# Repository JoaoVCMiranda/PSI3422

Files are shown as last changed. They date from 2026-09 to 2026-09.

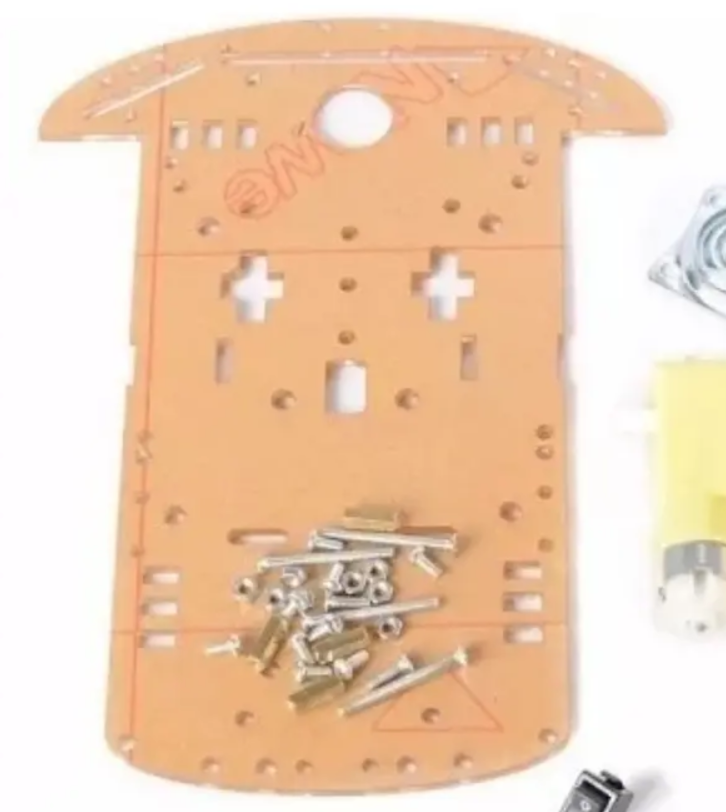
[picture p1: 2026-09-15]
experiências/Exp3_PSI3422/assets/desenho_chassi.png

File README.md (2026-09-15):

# Laboratório de Sistemas Eletrônicos

## Exp1 - Profª Yu

### Aula 1
- [X] Entregue, porém podemos fazer melhor

Objetivos:

    Programar o carrinho para: avançar, recuar e fazer curvas.
    Detectar obstáculos e desviar-se deles.

Roteiro:

    Conecte a ponte H aos motores e programe o carrinho para avançar/recuar;
    Controle a velocidade dos motores para fazer curvas.
    Programe o sensor ultrassom para detectar obstáculos e desviar-se deles. 

Última atualização: terça-feira, 4 ago. 2026, 08:45

### Aula 2
- [X] Entregue — ver `experiências/Exp2_PSI3422/` (Carrinho + Controle, nRF24L01+ via `lib/spi` e `lib/nrf24` compartilhadas)
Objetivos:

    Implementar a comunicação serial entre duas placas de desenvolvimento Freedom (KL25Z) utilizando os tranceivers nRF24L01+.
    Através do terminal do computador, controlar remotamente um LED na outra placa Freedom.

Roteiro:

    Implemente a comunicação serial entre duas placas de desenvolvimento Freedom (KL25Z) utilizando os tranceivers nRF24L01+.
    Conecte os dois transceptores às duas placas Freedom de acordo com as orientações da apresentação.
    OBS1: Lembre-se que a tensão máxima de alimentação do nRF24L01+ é de 3,6!
    OBS2: Verifique a versão do seu módulo nRF24L01, pois os pinos mudam dependendo da versão do componente.
    Programe os transceptores para receber/trasmitir dados.
    Conecte as duas placas no mesmo computador e utilize o Serial Monitor para verificar a comunicação.
    Através do terminal do computador, controle remotamente um LED na outra placa Freedom.

Observações:

    Os transceptores utilizam a comunicação SPI.
    Freedom KL25Z suporta a comunicação SPI.
    Além da comunicação SPI, os pinos CE e CSN (IRQ opcional) precisam ser configurados para transmitir/receber dados.
    Os comandos de operação estão listados no Datasheet do módulo.
    A apresentação mostra de forma sucinta como programar cada modo de operação do módulo.

Última atualização: terça-feira, 11 ago. 2026, 09:19 

### Aula 3 
- [X] Ficou massa!
Objetivos:

    Criar uma placa de circuito impresso para interconectar os módulos que serão usados no carrinho.
    Usando esta placa, o carrinho deverá receber um comando remoto para movimentar os motores.
    O carrinho deverá ser alimentado pela bateria.

Observações:

    Defina quais pinos serão utilizados por cada componente antes de criar a placa de circuito impresso.
    Tamanho recomendado para os furos das ilhas: 2 mm
    Tamanho recomendado para as trilhas: 1 mm

Componentes:

    Microcontrolador FRDM KL25Z
    Sensor ultrassônico HC-SR04
    Módulo de comunicação wireless nRF24L01+
    Motores (Ponte H)
    Encoder dos motores (consulte os objetivos da "Aula 4" para verificar o uso dos encoders neste projeto)

Última atualização: segunda-feira, 17 ago. 2026, 16:32
### Aula 4 
Objetivos:

    Acople um encoder(sensor de obstáculos IR HW-201) em cada motor.

    Calibre o encoder para estimar a distância percorrida pelo carrinho.
    Calibre o encoder para controlar o movimento do carrinho e fazer:
        Uma curva de 90° para direita;
        Uma curva de 90° para esquerda.
    OBS: Essa parece uma aplicação interessante de programação competitiva, um código que dados dois contadores de rotações para cada roda, calcule qual é a distância percorrida.

Última atualização: segunda-feira, 17 ago. 2026, 16:32

### Aula 5 e 6
Objetivos:

    Monte o Shield e os módulos do carrinho.
    Programação do carrinho para atravessar o percurso fechado por obstáculos e estimar a distância percorrida.

Comportamento esperado do carrinho na entrega final/apresentação:
Controle remoto pelo computador:

    Controle o carrinho de forma remota através da comunicação wireless:
        Adicione um comando para entrar no estado RUN.
        Adicione um comando para entrar no estado STOP.
        Adicione um comando para mostrar a distância percorrida no computador.
        Adicione um comando para apagar a distância percorrida salvo no carrinho.

Funções no estado RUN:

    Crie uma lógica para o carrinho atravessar um labirinto.
    O carrinho pode avançar, recuar e fazer curvas.
    Estime e salve a distância percorrida (dar meia-volta não reduz a distância percorrida).

Funções no estado STOP:

    O carrinho fica parado e aguarda novas instruções.

Última atualização: segunda-feira, 17 ago. 2026, 19:55

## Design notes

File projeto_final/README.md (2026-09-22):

# projeto_final — consolidação de produção (Aulas 3-6)

Reúne os módulos "de produção" do carrinho — firmware, portmap único
e o ponto de partida da PCB — cobrindo o roteiro das Aulas 3 a 6 do
`README.md` raiz. Arquitetura: par **Carrinho + Controle** (like
`experiências/Exp2_PSI3422/`), não um board único — ver módulos abaixo.

## Fonte única do portmap

`pinmap.yaml` é a fonte de verdade dos pinos da FRDM-KL25Z (Carrinho
e Controle). `python3 tools/gen_pinmap.py` (de dentro desta pasta)
gera, de forma determinística:

- `pinmap.h` — incluído por `Carrinho/src/main.c` e
  `Controle/src/main.c`.
- `Pinmap.md` — tabela por board (substitui a manutenção manual
  duplicada em `experiências/Exp2_PSI3422/Pinmap.md` e
  `experiências/Exp4_PSI3422/pinmap.md`).
- `kicad/PSI3422_shield.kicad_sym` — símbolo KiCad do shield, ainda
  não reconciliado com o projeto KiCad de verdade (`kicad/Aula3_PCB.*`,
  movido de `experiências/Exp3_PSI3422/Kicad/`) — ver `kicad/README.md`
  pro estado de cada um e o próximo passo (validar no KiCad, que já
  está instalado nesta máquina agora, e unificar os dois símbolos).

Editar `pinmap.yaml`, nunca os três arquivos gerados.

## Protocolo — `protocol.h`

Extensão mínima de `experiências/Exp2_PSI3422/protocol.h`: RUN/STOP
reaproveitam `auto_mode`/`freio` (já existiam); dois campos novos —
`apagar_seq` (comando) e `dist_percorrida_cm` (telemetria) — cobrem
"mostrar distância"/"apagar distância" do roteiro. Ver comentários em
`protocol.h` pro racional de cada um.

## Carrinho/

Zephyr, FRDM-KL25Z. Junta `experiências/Exp2_PSI3422/Carrinho`
(motores, ultrassom, rádio, `lib/control_fsm`) com
`experiências/Exp4_PSI3422/CarrinhoBase` (encoder + `lib/odometria`)
por cima, sem mudar a lógica de nenhum dos dois — só a fiação entre
eles em `src/main.c`. `lib/control_fsm/` é cópia verbatim do Exp2 (não
precisou de mudança: "apagar distância" é tratado direto em
`main.c`, não dentro do FSM).

Só `ENCODER_R` está no pinmap atual — o carrinho não tem mais o
encoder esquerdo fisicamente montado. `lib/odometria` (contrato de
odometria diferencial, dois deltas) não foi alterada: `src/main.c`
passa o delta de `ENCODER_R` pros dois parâmetros, o que zera
`theta_rad` (campo não usado hoje) e mantém `distancia_percorrida_m`
correta. Ver comentário no topo de `Carrinho/src/main.c`.

**RUN** = `auto_mode` (desvio reativo por ultrassom frontal, 4
faixas) — é a "travessia de labirinto" cabível com um único sensor de
distância (frontal, sem mapeamento). **STOP** = `freio`.

### Parâmetros do carrinho

Distância entre as rodas: 17cm
Raio da roda: 3.5cm

## Controle/

Cópia de `experiências/Exp2_PSI3422/Controle` com duas teclas novas
em `key_to_cmd()`/`main()`: `i` (mostrar distância percorrida,
imprime a última telemetria já em cache — sem round-trip de rádio
novo) e `c` (apagar distância). `w/a/s/d/x/espaço/q/o` seguem iguais;
`o`/`x` agora nomeados explicitamente RUN/STOP no banner de boot.

Joystick continua desabilitado no código (defeito de hardware
confirmado, ver `experiências/Exp2_PSI3422/PENDENCIAS.md`) — UART
(`script/controle_serial.py`) é o caminho de comando.

## Monitoramento/

Terceiro board: só rádio nRF24L01+ em modo recepção — ouve a
telemetria (`radio_telemetry_t`) que o Carrinho já transmite a cada
ciclo (~50ms) e imprime `dist`/`dutyL`/`dutyR`/`percorrida`, sem
transmitir nenhum `radio_cmd_t` (isso continua sendo papel exclusivo
do Controle). Primeiro passo do roteiro de debug em ciclos rápidos:
recepção de metadados -> conferir contagem de distância -> conferir
o modelo de desvio do Carrinho resolvendo o percurso -> percurso real
(geometria a definir).

Mesmo pinmap de rádio/LEDs de Carrinho/Controle (`../pinmap.h`).
CAVEAT não validado em bancada: endereço/canal do nRF24 são únicos e
fixos pro projeto inteiro (`lib/nrf24/nrf24.c`) e auto-ACK está
ligado — com três rádios (Carrinho, Controle, Monitoramento) no
mesmo endereço/canal, Monitoramento passa a mandar ACK pros pacotes
do Carrinho ao mesmo tempo que o Controle, o que pode colidir no ar
e aumentar reenvios/timeouts vistos pelo Carrinho. Não deveria
derrubar o link (retransmissão já existe), mas fica por confirmar
com os três rádios ligados juntos.

## Pendente (fora desta rodada)

- ~~**`nrf24_init()` sempre retornava -134 (-ENOTSUP)**~~ RESOLVIDO
  (sessão de 22/09/2026) — provável causa raiz de TODO o histórico de
  "rádio não conecta" do projeto. `nrf24_init()` chamava
  `gpio_pin_interrupt_configure_dt(&nrf24_irq, GPIO_INT_EDGE_TO_ACTIVE)`
  em RADIO_IRQ (PTB8, PORTB). Neste board/framework
  (`dts/arm/nxp/nxp_kl25z.dtsi`), só `gpioa` (PORTA) e `gpiod`
  (PORTD) têm a property `interrupts` — `gpiob`/`gpioc`/`gpioe` não;
  o driver (`drivers/gpio/gpio_mcux.c`) só liga `GPIO_INT_ENABLE`
  quando essa property existe, e sem ela
  `gpio_pin_interrupt_configure()` retorna `-ENOTSUP` (-134) pra
  qualquer pino do port. Como RADIO_IRQ está em PORTB, essa chamada
  **sempre falhava**, e o `if (ret < 0) return ret;` logo depois
  fazia `nrf24_init()` abortar ali — `nrf24_configure()` (endereço,
  canal, CRC) nunca rodava, CE nunca ia pra 1: o rádio nunca foi
  configurado de verdade, em nenhum board, em nenhuma sessão. A
  interrupção era código morto (o semáforo que ela dispararia nunca
  era esperado em lugar nenhum — `nrf24_send()`/`nrf24_receive()` só
  fazem polling direto de `gpio_pin_get_dt()`), removida de
  `lib/nrf24/nrf24.c` — RADIO_IRQ agora só é `GPIO_INPUT` comum, sem
  callback/interrupção. `pio run` verificado em todos os projetos que
  usam `lib/nrf24` depois do fix. Ainda sem validação de bancada —
  mas isso muda completamente a prioridade dos diagnósticos SPI
  (`nrf24_read_status()`) e de timing/protocolo levantados antes:
  aquilo tudo era irrelevante enquanto o rádio nem chegava a ser
  inicializado.
- ~~**Dois pinmaps (`pinmap.yaml` vs `pinmap_carrinho.yaml`)**~~
  RESOLVIDO (sessão de 22/09/2026): a hipótese era que a PCB do
  Carrinho tinha o nRF24 fiado em PTD6/PTB9/PTD7 (commit 6e70945),
  diferente do Controle (fiado à mão em PTC5/PTC6/PTC7, o que
  `pinmap.yaml` atual documenta). `nrf24_read_status()` confirmou:
  status travado em `0xFF` nos DOIS boards — SPI0 de hardware só
  existe em PORTC/PORTA nesta família de chip, então PTD6/PTB9/PTD7
  nunca poderia funcionar por SPI0 em nenhum dos dois. Os fios do
  módulo nRF24 foram movidos fisicamente pra PTC5/PTC6/PTC7 nos dois
  boards — `debug_projeto_final`, `debug_projeto_final_controle` e
  `projeto_final/Carrinho` voltaram a usar `pinmap.h` (não
  `pinmap_carrinho.h`). `pinmap_carrinho.yaml`/`.h`/`.md`/símbolo
  KiCad ficam só como registro histórico do que a PCB tinha antes do
  rework, não são mais a referência ativa. `tools/gen_pinmap.py`
  continua aceitando um YAML alternativo como argumento, caso sirva
  de novo no futuro.
- ~~**RADIO_SCK/MOSI/MISO documentados errado em pinmap.yaml**~~
  RESOLVIDO (sessão de 22/09/2026): pinmap.yaml dizia PTD6/PTB9/PTD7,
  mas `nrf24_init()` chama `spi_init(SPI_0, ALT_0, ...)`
  (`lib/spi/spi.c`), que hardcoda PTC5/PTC6/PTC7 via CMSIS direto —
  as únicas duas rotas de hardware do SPI0 na KL25Z são PORTC (ALT_0)
  ou PORTA (ALT_1), então PTD6/PTB9/PTD7 nunca foi uma opção válida
  (erro de digitação antigo, não uma rota alternativa real).
  `pinmap.yaml`/`Pinmap.md` corrigidos pra PTC5/PTC6/PTC7 — esses
  pinos são `tipo: doc` (spi_init() não passa por devicetree, sem
  define em pinmap.h), então a correção não muda nenhum binário, só a
  documentação. **Mas se o shield físico foi roteado pelos valores
  antigos (PTD6/PTB9/PTD7), o SPI do rádio está fisicamente errado na
  placa** — conferir continuidade PTC5→SCK/PTC6→MOSI/PTC7→MISO do
  nRF24L01+ é prioridade de bancada, antes de qualquer outro debug de
  rádio (se for isso, explicaria falha de conexão de forma muito mais
  direta que qualquer hipótese de timing).
- ~~**Canais PWM dos motores trocados**~~ RESOLVIDO (sessão de
  22/09/2026): `debug/debug_ponte_H_encoder/src/main.c` já tinha
  descoberto e corrigido isso em bancada ("MOTOR_L_ENA_CH/MOTOR_R_ENB_CH
  estavam trocados"), mas a correção nunca voltou pro `pinmap.yaml` de
  produção. Confirmado de forma independente contra o datasheet
  (`MKL25Z128VLK4-pinctrl.dtsi`): PTD2 (MOTOR_L_ENA) é fisicamente
  TPM0_CH2, não CH1; PTA4 (MOTOR_R_ENB) é TPM0_CH1, não CH2. Com os
  canais trocados, o duty de cada motor saía fisicamente no pino do
  *outro* motor (direção in1/in2 continuava certa — só a velocidade
  ficava cruzada) — candidato forte pra explicar "carrinho anda torto"
  (PENDENCIAS.md do Exp2). `pinmap.yaml` corrigido e
  `pinmap.h`/`Pinmap.md` regerados via `gen_pinmap.py`; `pio run`
  verificado nos três projetos depois do fix. Ainda sem confirmação em
  bancada com o carrinho de verdade.
- ~~**Leitura dupla do ultrassom em auto_mode**~~ RESOLVIDO (mesma
  sessão): `Carrinho/src/main.c` já chama `ultrassom_read()` a cada
  ciclo (telemetria); `control_fsm_apply()` chamava de novo
  internamente em auto_mode, cada chamada bloqueando até
  `ECHO_TIMEOUT_MS` (30ms) — quase dobrava a latência da malha de
  desvio reativo. `control_fsm.c` agora reusa `sensor->distance` (já
  atualizado por main.c) em vez de disparar o sensor de novo.
- **`nrf24_receive(timeout)` era ignorado**: a implementação sempre
  esperava 100ms fixos, não importa o valor passado — sem efeito
  observável hoje (todo chamador usa `K_MSEC(100)`), mas quebraria em
  silêncio um `K_FOREVER`/outro valor. Corrigido em `lib/nrf24/nrf24.c`
  pra usar o `timeout` de verdade (`K_TICKS_FOREVER` tratado à parte).
- **Colisão de ACK com 3 rádios (caveat do `Monitoramento/`)**:
  mitigado, não eliminado — `lib/nrf24` ganhou `nrf24_set_auto_ack()`
  (liga/desliga EN_AA sem reconfigurar o resto do rádio) e
  `Monitoramento/src/main.c` desliga o próprio auto-ACK logo após
  `nrf24_init()` (e de novo a cada reconexão). Como Monitoramento só
  recebe, nunca precisou responder ACK — agora só o Controle responde,
  eliminando a colisão por construção em vez de só confiar em
  retransmissão. Ainda sem teste de bancada com os três rádios ligados
  juntos.
- ~~**Build verificado**~~ RESOLVIDO: causa raiz não era a máquina nem
  a instalação (pip vs. `uv tool install platformio`) — era
  `platform = freescalekinetis` sem versão em cada `platformio.ini`,
  que sempre resolve pra última release do registry. Isso "funcionava
  por acidente" enquanto a última release continuava pinando
  `framework-zephyr ~2.20701.0` (Zephyr 2.7.1, API antiga
  `#include <zephyr.h>`, a que todo o código daqui e do Exp2/Exp4
  usa). Em 31/08/2026 o registry publicou
  `freescalekinetis@11.0.0`, que pina `framework-zephyr ~3.40402.0`
  (Zephyr 4.4.2, exige `#include <zephyr/...>`) — dali em diante
  qualquer `pio run` nesta família de projetos passou a falhar,
  inclusive includes relativos (`../../protocol.h` etc.), porque a
  falha no primeiro `#include <zephyr.h>` aborta a unit de compilação
  antes de chegar nos outros. `Carrinho/`, `Controle/` e
  `Monitoramento/` agora pinam `platform = freescalekinetis@10.0.0`
  (última versão que pina Zephyr 2.7.1) em `platformio.ini` — `pio
  run` verificado com sucesso nos três (`[SUCCESS]`, firmware.elf/.bin
  gerados) nesta máquina. `experiências/Exp1-4_PSI3422/` continuam
  sem o pin — mesmo problema vai aparecer lá se alguém rodar `pio run`
  neles agora.
- **Validação de bancada**: RUN (desvio reativo) nunca rodou em
  carrinho de verdade (herdado do Exp2, ver PENDENCIAS.md); comandos
  `i`/`c` novos, sem teste com hardware. `Monitoramento/` (recepção
  de telemetria) também sem teste com hardware — inclui o caveat de
  colisão de ACK com três rádios, ver seção acima.
- **Calibração da odometria**: `Carrinho/src/main.c` atualizado para
  as medidas reais (17cm entre rodas, roda raio 3,5cm — ver seção
  "Parâmetros do carrinho" acima), substituindo as estimativas
  antigas (20cm/5cm) herdadas do Exp4. Ainda sem validação de bancada
  do valor absoluto de `dist_percorrida_cm` contra uma distância
  conhecida percorrida — é o próximo passo do roteiro (ver
  `Monitoramento/`, acima).
- **Chassi 3D**: decisão adiada (`experiências/Exp3_PSI3422/`,
  `modelo_1`/`modelo_2`) — fora do escopo desta rodada.
- **PCB**: `kicad/Aula3_PCB.kicad_pcb` já tem uma placa roteada, mas o
  esquemático (`.kicad_sch`) está praticamente vazio e o símbolo
  gerado (`PSI3422_shield.kicad_sym`) ainda não foi conciliado com o
  símbolo real (`FRDM-KL25Z.kicad_sym`) usado nela — validar abrindo
  no KiCad (já instalado) é o próximo passo, ver `kicad/README.md`.
- **Distância "salva"**: acumulador em RAM (`odometria_pose_t`), não
  sobrevive a reboot — suficiente pro roteiro por decisão explícita
  (sem NVS/flash).

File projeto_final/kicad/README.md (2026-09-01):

# kicad/ — PCB do shield

Dois conjuntos de arquivos aqui, ainda não reconciliados entre si
(próximo passo, ver "Pendente" no fim):

- **`Aula3_PCB.*`, `FRDM-KL25Z.kicad_sym`/`.kicad_mod`,
  `design-block-lib-table`, `model.png`** — projeto KiCad de verdade
  (movido de `experiências/Exp3_PSI3422/Kicad/`), com PCB já roteada
  (`Aula3_PCB.kicad_pcb`, ~5400 linhas) e um símbolo/footprint
  dedicado da FRDM-KL25Z. `Aula3_PCB.kicad_sch` ainda é praticamente
  vazio (13 linhas) — o trabalho até aqui parece ter ido direto pro
  editor de PCB.
- **`PSI3422_shield.kicad_sym`** — **gerado** por
  `../tools/gen_pinmap.py` a partir de `../pinmap.yaml` (mesma fonte
  que gera `../pinmap.h`, usado pelo código de `Carrinho`/`Controle`).
  Não editar à mão: editar o YAML e rodar
  `python3 tools/gen_pinmap.py` de dentro de `projeto_final/`.

KiCad 9.0.2 já está instalado nesta máquina (`kicad-cli` disponível) —
ainda não usei pra abrir/validar nenhum dos dois conjuntos de verdade,
fica pro próximo passo.

## Pendente (próxima rodada, avisado pelo usuário)

- **Validar** `Aula3_PCB.*` abrindo no KiCad de verdade — inclui
  conferir `design-block-lib-table`, que aponta pra um caminho
  absoluto do Windows (`C:/Users/caean/Desktop/FRDM-KL25Z ver6`,
  provavelmente de onde o símbolo/footprint originais vieram) —
  provavelmente inofensivo (metadado de biblioteca de "design
  blocks", não usado pelo `.kicad_pcb` em si) mas não confirmado ainda.
- **Single source of truth**: hoje `pinmap.yaml`/`gen_pinmap.py`
  geram um símbolo próprio (`PSI3422_shield.kicad_sym`) só com os
  sinais do portmap, separado do símbolo `FRDM-KL25Z` de verdade usado
  no `Aula3_PCB.kicad_sch`/`.kicad_pcb`. Reconciliar os dois é o
  próximo passo — provavelmente gerar os pinos DENTRO do símbolo
  `FRDM-KL25Z.kicad_sym` já usado na PCB real, em vez de manter dois
  símbolos paralelos.

## O que o gerador NÃO faz (trabalho manual que continua no KiCad)

- Adicionar os footprints dos outros componentes do shield: ponte H
  (L298N ou similar), HC-SR04, módulo nRF24L01+, os dois HW-201 —
  esses não têm pino fixo na KL25Z (são módulos externos conectados
  pelos sinais do símbolo gerado), então entram como símbolos/
  footprints padrão de biblioteca KiCad, não gerados daqui.
- Desenho elétrico dos módulos e roteamento físico exigem julgamento
  humano (posicionamento, trilhas de potência dos motores separadas
  das de sinal, etc.) — o gerador só resolve a parte mecânica de
  derivar pinos do portmap, não substitui isso.

Isso cobre a pendência da Aula 3 (`README.md` raiz) até o ponto onde
dá pra automatizar a partir do portmap.

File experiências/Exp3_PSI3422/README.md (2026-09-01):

Aqui haverá a modelagem feita em KiCAD para imprimirmos

E também o chassi modelado com o OpenSCAD

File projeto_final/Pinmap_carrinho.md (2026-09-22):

# Pinmap — projeto_final (FRDM-KL25Z)

GERADO por `tools/gen_pinmap.py` a partir de `pinmap.yaml` — não
editar à mão, editar o YAML e rodar o gerador de novo. Substitui a
manutenção manual de `experiências/Exp2_PSI3422/Pinmap.md` e
`experiências/Exp4_PSI3422/pinmap.md` (quase duplicados) por uma
fonte única, que também gera `pinmap.h` e o símbolo KiCad.

## Carrinho

| Sinal | Pino | Tipo/Direção | Observação |
|---|---|---|---|
| MOTOR_L_IN1 | PTD0 | saida | Ponte H, direção do motor esquerdo (lib/motor) |
| MOTOR_L_IN2 | PTC9 | saida | Ponte H, direção do motor esquerdo (lib/motor) |
| MOTOR_L_ENA | PTD2 | pwm | TPM0_CH2, velocidade do motor esquerdo, via lib/pwm_z42 (canal corrigido — ver debug/debug_ponte_H_encoder/src/main.c) |
| MOTOR_R_IN1 | PTC8 | saida | Ponte H, direção do motor direito (lib/motor) |
| MOTOR_R_IN2 | PTA5 | saida | Ponte H, direção do motor direito (lib/motor) |
| MOTOR_R_ENB | PTA4 | pwm | TPM0_CH1, velocidade do motor direito, via lib/pwm_z42 (canal corrigido — ver debug/debug_ponte_H_encoder/src/main.c) |
| ULTRASSOM_TRIG | PTD3 | saida | HC-SR04 trigger (lib/ultrassom) |
| ULTRASSOM_ECHO | PTD1 | entrada_irq | HC-SR04 echo, interrupção de borda (lib/ultrassom) |
| ENCODER_L | PTD1 | entrada_irq | IR HW-201 esquerda (lib/encoder) |
| ENCODER_R | PTA16 | entrada_irq | IR HW-201 direita (lib/encoder) |
| RADIO_SCK | PTD6 | fixo | valor de 6e70945 — ver aviso no topo do arquivo, spi_init() atual não bate com isso |
| RADIO_MOSI | PTB9 | fixo | idem RADIO_SCK |
| RADIO_MISO | PTD7 | fixo | idem RADIO_SCK |
| RADIO_CSN | PTB10 | saida | chip-select manual do nRF24 (lib/nrf24) |
| RADIO_CE | PTE31 | saida | lib/nrf24 |
| RADIO_IRQ | PTB8 | entrada_irq | ativo em LOW (lib/nrf24) |
| LED_RED | PTB18 | saida | active low |
| LED_GREEN | PTB19 | saida | active low |

## Controle

| Sinal | Pino | Tipo/Direção | Observação |
|---|---|---|---|
| RADIO_CSN | PTB10 | saida | chip-select manual do nRF24 (lib/nrf24) |
| RADIO_CE | PTE31 | saida | lib/nrf24 |
| RADIO_IRQ | PTB8 | entrada_irq | ativo em LOW (lib/nrf24) |
| LED_RED | PTB18 | saida | active low |
| LED_GREEN | PTB19 | saida | active low |
| CONSOLE_UART0 | PTA1 | fixo | PTA1/PTA2 (RX/TX), console fixo via devicetree (zephyr,console) — comandos via script/controle_serial.py |
| JOYSTICK_X | PTB0 | adc | ADC0_SE8 — defeito de hardware conhecido, ver PENDENCIAS.md |
| JOYSTICK_Y | PTB1 | adc | ADC0_SE9 |
| JOYSTICK_BTN | PTB2 | entrada | botão de freio, pull-up interno, active low |

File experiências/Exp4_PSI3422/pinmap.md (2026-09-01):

# Pinmap — Exp4_PSI3422 (CarrinhoBase, FRDM-KL25Z)

Mesmo chassi/pinagem de motores da Exp2_PSI3422 (ver `../Exp2_PSI3422/Pinmap.md`) — a Aula 4 só acopla os encoders IR HW-201, já reservados em PORTD desde a Exp2 (`debug/EncoderCheck`). Sem rádio nem ultrassom neste projeto: o escopo da Aula 4 é ponte H + contadores de volta com sinal, não o carrinho completo.

| Sinal | Pino | Observação |
|---|---|---|
| Motor L — IN1 | PTC8 | GPIO |
| Motor L — IN2 | PTC9 | GPIO |
| Motor L — ENA (PWM) | PTA4 | TPM0_CH1, via `lib/pwm_z42` |
| Motor R — IN1 | PTA12 | GPIO |
| Motor R — IN2 | PTD5 | GPIO |
| Motor R — ENB (PWM) | PTA5 | TPM0_CH2, via `lib/pwm_z42` |
| Encoder IR HW-201 — esquerda | PTD1 | GPIO entrada, interrupção de borda de subida |
| Encoder IR HW-201 — direita | PTD3 | GPIO entrada, interrupção de borda de subida |

`gpioc` não vem habilitado por padrão neste board (só `gpioa/b/d`) — ligado em `zephyr/boards/frdm_kl25z.overlay`, mesmo motivo do overlay da Exp2. `gpiod` já é default, não precisa de overlay para os encoders.

Encoders: mesma escolha de pino da Exp2 (PTD1/PTD3) — só PORTA e PORTC/PORTD geram interrupção por mudança de pino nesta subfamília KL25Z (PORTB/PORTE não, confirmado em bancada). Ver `lib/SPEC.md`, seção `encoder/`, para o racional de como o sentido (frente/ré) é inferido do comando do motor.

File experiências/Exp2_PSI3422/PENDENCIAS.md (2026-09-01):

# Pendências — Exp2_PSI3422

Snapshot do que falta, pra retomar sem precisar releer a conversa toda. `main` = entrega real (Atividade 2 já entregue, README Aula 2). `debug/exp2-validacoes` = bancada de validação, não mergeada.

## Hardware — bloqueando

- **Joystick (Controle) com defeito confirmado**: eixo travado perto de 3,3V/4095 (medido com multímetro e com `debug/JoystickCheck`). `joystick_read()` está desabilitado de novo no `main` (só UART funciona). Falta:
  - Rodar o teste de troca cruzada (trocar os fios X/Y) e o teste de continuidade no potenciômetro pra saber se é o pot ou a fiação do lado do KL25Z.
  - Depois de consertar, reativar a chamada comentada em `Controle/src/main.c` (`joystick_read(&ml, &mr, &brk);`) e revalidar com `debug/JoystickCheck`.

- **Carrinho anda torto** (uma roda com mais força/torque que a outra), confirmado com `debug/AlinhamentoCheck`. Já verificado que não é bug de firmware (`pwm_z42.c`/`motor.c` escrevem o mesmo duty nos dois canais TPM). Falta:
  - Rodar `debug/DutySweepCheck` (torque de arranque por motor) — construído, ainda não testado/reportado.
  - Rodar `debug/EncoderCheck` depois de instalar os HW-201 (pulsos/s por roda no mesmo duty) — construído, aguardando hardware.
  - Teste manual de troca cruzada dos motores (isola motor vs. ponte H/fiação) e teste com rodas no ar (isola elétrico vs. mecânico/atrito) — sugeridos, ainda não reportados.

## Branch debug/exp2-validacoes — não mergeada em main

- `JoystickCheck`, `AlinhamentoCheck`, `DutySweepCheck`, `EncoderCheck`, `monitor.py`: só existem aqui, não em `main`. Decidir quando (ou se) algo disso vale trazer pra `main` — provavelmente não os firmwares em si (são só bancada), mas:
- **Reserva de pinos dos encoders (PTD1/PTD3) no `Pinmap.md`** está só nesta branch. Levar pra `main` assim que os HW-201 forem instalados e `EncoderCheck` confirmar que os pinos funcionam de verdade.
- `debug/monitor.py`: comentário na linha ~73 ainda cita `DISTANCIA_MINIMA_M`, renomeada pra `DISTANCIA_FRENTE_M`/`DISTANCIA_CURVA_M`/`DISTANCIA_PARADA_M` no commit `4b3ff74` (main). Só comentário, não quebra nada — cosmético.

## auto_mode (control_fsm) — implementado, não testado com hardware real

Commit `4b3ff74` em `main` trocou o auto_mode binário por 4 faixas de distância (frente/vira direita/ré/para). Buildado com sucesso, mas **nunca rodado no carrinho de verdade** — validar:
- Os limiares (30/20/4cm) fazem sentido com o alcance/precisão real do HC-SR04 nesta montagem.
- O pivô de giro (`motor_l` frente + `motor_r` ré) realmente vira pra direita no sentido físico esperado (não foi conferido em bancada, só a lógica).
- Se `VELOCIDADE_AUTO` (~50%) é uma velocidade seguras pra virar/dar ré sem capotar ou perder tração.

## README — próximas aulas ainda não iniciadas

- **Aula 3** (`- [ ] Por Fazer`): projetar a PCB de verdade. `Pinmap.md` já cobre boa parte do "defina os pinos antes de criar a placa", mas falta o desenho da placa em si.
- **Aula 4** (sem checkbox — não iniciada): acoplar os HW-201, calibrar distância percorrida a partir da contagem de pulsos, fazer curvas de 90° calibradas. `debug/EncoderCheck` é um adiantamento de bancada pra isso, não a entrega.
- **Aula 5/6** (sem checkbox — não iniciada): comandos RUN/STOP remotos, travessia de labirinto, distância salva/apagável.

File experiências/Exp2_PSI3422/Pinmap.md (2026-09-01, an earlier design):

# Pinmap — Exp2_PSI3422 (Carrinho + Controle, FRDM-KL25Z)

Validado por build real (`pio run` em ambos os projetos) e pelos `#define` em cada `src/main.c` — não pelo diagrama Arduino do board (os headers D-numerados não batem com os pinos reais usados aqui).

Nem SPI nem TPM têm nó de devicetree neste port (Zephyr 2.7.1 empacotado pelo PlatformIO — conferido em `dts/arm/nxp/nxp_kl25z.dtsi`). Por isso o rádio usa `lib/spi` bare-metal em vez de `spi_dt_spec`, e os motores usam `pwm_z42` em vez de `pwm_dt_spec`. `gpioc`/`gpioe` também não vêm habilitados por padrão (só `gpioa/b/d`) — cada projeto liga isso em `zephyr/boards/frdm_kl25z.overlay`.

## Carrinho

| Sinal | Pino | Observação |
|---|---|---|
| Motor L — IN1 | PTC8 | GPIO |
| Motor L — IN2 | PTC9 | GPIO |
| Motor L — ENA (PWM) | PTA4 | TPM0_CH1, via `pwm_z42` |
| Motor R — IN1 | PTA12 | GPIO |
| Motor R — IN2 | PTD5 | GPIO |
| Motor R — ENB (PWM) | PTA5 | TPM0_CH2, via `pwm_z42` |
| Ultrassom — TRIG | PTD0 | GPIO saída |
| Ultrassom — ECHO | PTD4 | GPIO entrada, interrupção |
| Rádio — SCK/MOSI/MISO | PTC5/PTC6/PTC7 | SPI0 bare-metal (`lib/spi`, `ALT_0`) |
| Rádio — CSN | PTC4 | GPIO, chip-select manual |
| Rádio — CE | PTA13 | GPIO |
| Rádio — IRQ | PTD2 | GPIO entrada, interrupção ativa em LOW |
| LED status (vermelho/verde) | PTB18 / PTB19 | Active low |
| Encoder IR HW-201 — esquerda (reservado) | PTD1 | GPIO entrada, interrupção — ver `debug/EncoderCheck` |
| Encoder IR HW-201 — direita (reservado) | PTD3 | GPIO entrada, interrupção — ver `debug/EncoderCheck` |

Encoders: ainda não instalados fisicamente (Aula 4). Reservados em PORTD de propósito — nesta subfamília KL25Z só PORTA e PORTC/PORTD têm vetor de interrupção de pino; PORTB/PORTE não geram IRQ por mudança de pino (confirmado na bancada: `gpioe` como IRQ deu problema). PTD1/PTD3 ficam nos "buracos" entre os pinos de PORTD já usados (TRIG=PTD0, IRQ do rádio=PTD2, ECHO=PTD4, motor R IN2=PTD5), mesmo port já comprovado como fonte de interrupção.

## Controle

| Sinal | Pino | Observação |
|---|---|---|
| Rádio — SCK/MOSI/MISO | PTC5/PTC6/PTC7 | SPI0 bare-metal (`lib/spi`, `ALT_0`) |
| Rádio — CSN | PTC4 | GPIO, chip-select manual |
| Rádio — CE | PTA13 | GPIO |
| Rádio — IRQ | PTD2 | GPIO entrada, interrupção ativa em LOW |
| LED status (vermelho/verde) | PTB18 / PTB19 | Active low |
| Console (UART0) | PTA1/PTA2 | fixo, reservado, `printk` + comandos via `script/controle_serial.py` |
| Joystick — X | PTB0 | ADC0_SE8, `adc_channel_cfg`/`adc_sequence` (padrão de `PSI3441/entregas/4`) |
| Joystick — Y | PTB1 | ADC0_SE9, idem |
| Joystick — Botão de freio | PTB2 | GPIO entrada, pull-up interno, active low |

Pinos do joystick: não passaram por build real (`pio run`) ainda, só pelo padrão comprovado do PSI3441 Ativ.4 — nesta bancada o eixo já foi visto travado em 3,3 V/4095 (ver aviso em `Controle/src/main.c`).

## TPM disponível

A KL25Z tem 3 módulos TPM (`TPM0`: 6 canais, `TPM1`/`TPM2`: 2 canais cada — 10 no total). O Carrinho usa só 2 canais de `TPM0`; sobra folga para experiências futuras.

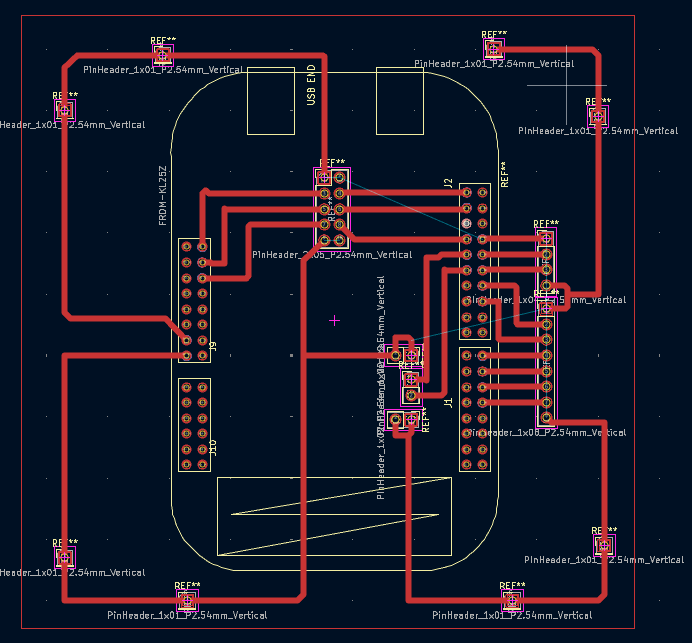
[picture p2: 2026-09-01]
projeto_final/kicad/model.png

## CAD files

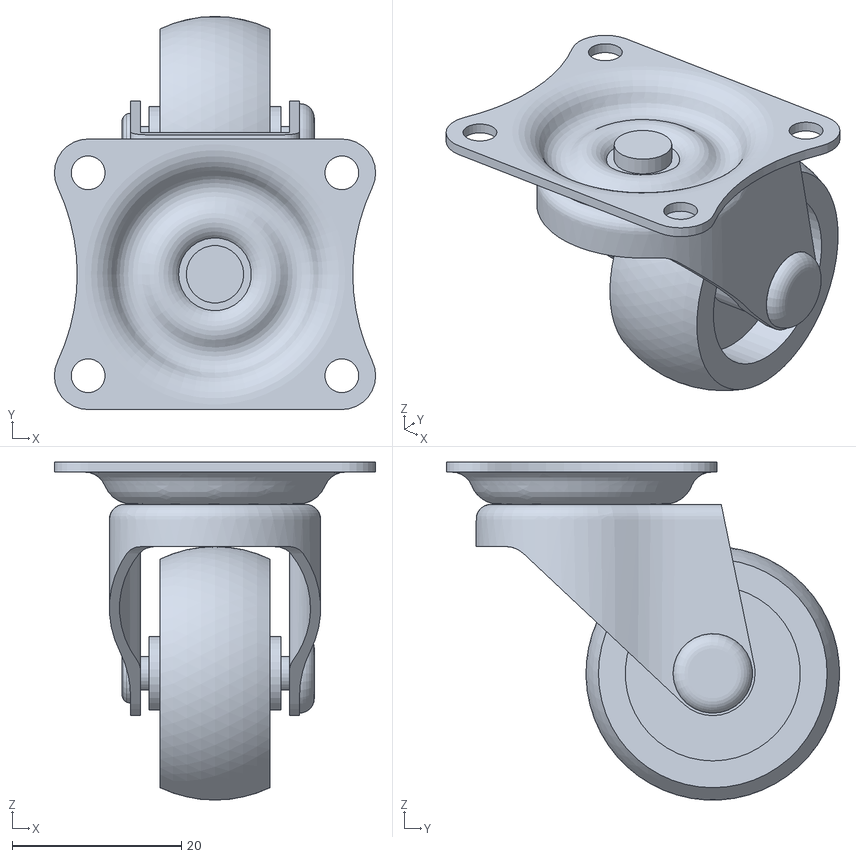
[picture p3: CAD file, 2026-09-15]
experiências/Exp3_PSI3422/assets/2wd_robot/caster.stl
38.0 x 46.5 x 40.0

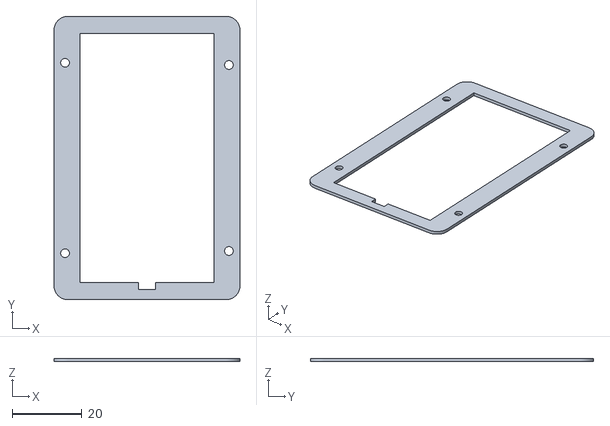
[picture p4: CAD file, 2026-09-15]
experiências/Exp3_PSI3422/assets/freescale_kl25z_drilling_guide.stl
53.3 x 81.3 x 1.00

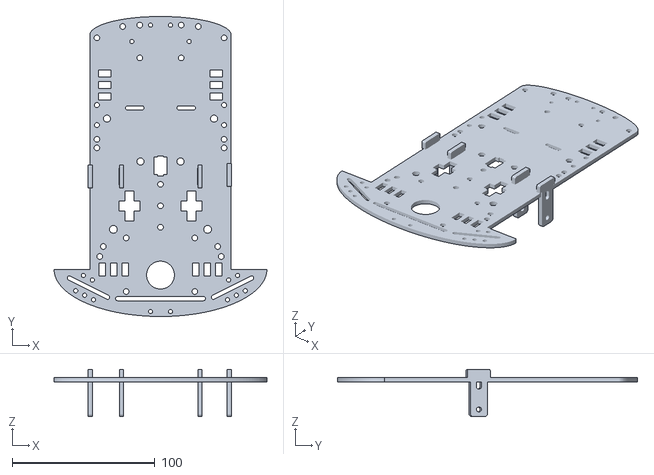
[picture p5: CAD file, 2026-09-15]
experiências/Exp3_PSI3422/assets/2wd_robot/chassis_plate.stl
149.0 x 210.0 x 33.0

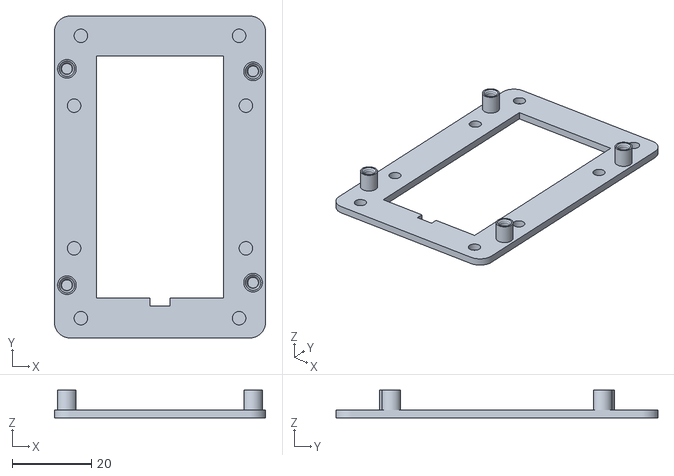
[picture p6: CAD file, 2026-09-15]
experiências/Exp3_PSI3422/assets/freescale_kl25z_mounting_plate.stl
53.3 x 81.3 x 7.00

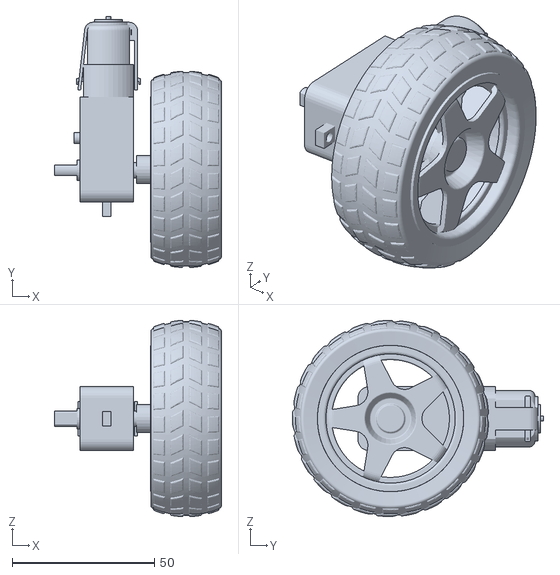
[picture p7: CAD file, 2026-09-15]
experiências/Exp3_PSI3422/assets/2wd_robot/motor_r.stl
58.8 x 88.2 x 68.9

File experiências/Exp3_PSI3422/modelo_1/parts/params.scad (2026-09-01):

include <BOSL2/std.scad>

$fs = 0.5;
$fa = 2;

// ============================================================
// PARÂMETROS DO CHASSI — Chassi 2WD REF: 7MS10 (MakerHero)
// Fonte única de verdade (mm). Valores marcados // ASSUNÇÃO foram
// estimados a partir da foto (assets/desenho_chassi.png) e das specs
// publicadas do kit, não de medição direta na peça física — conferir
// com paquímetro antes de mandar cortar a chapa definitiva.
// ============================================================

// --- Placa base (acrílico, corte a laser) ---
// A silhueta real vem de assets/2wd_robot/chassis_plate.stl (extraída do
// projeto de referência baixado pelo usuário — objeto "RobotChassis.001"
// isolado do .blend original via Blender). plate_length/plate_width abaixo
// são só a bounding box dessa peça real, usados como placeholder rápido
// durante $preview — a silhueta de verdade (com TODOS os furos e recortes
// originais do kit) é importada diretamente em base_plate.scad.
chassis_ref_stl       = "../assets/2wd_robot/chassis_plate.stl";
plate_length          = 210;  // bounding box real (medida no STL de referência)
plate_width           = 149;  // bounding box real
plate_thickness       = 3;    // spec do kit — ASSUNÇÃO (STL de referência não informa espessura real)

// --- Tração ---
// Coordenadas REAIS lidas no STL de referência (não são mais estimativa):
// os dois recortes em cruz do motor ficam em x=-100.05, y=±(48.5~52.3).
// NOTA IMPORTANTE: esse afastamento (~100mm entre os centros dos motores)
// diverge do wheelbase de 200mm medido no carrinho dos Exp2/Exp4 — ou o
// carrinho real não é um 7MS10 padrão, ou o valor medido é outra referência.
// PENDENTE de reconciliação com o firmware de odometria.
wheelbase_measured_exp2_4 = 200; // só documentado, não usado no modelo
wheel_diameter        = 68;   // spec do kit — diverge do raio 5cm (Ø100mm) do firmware, ver nota acima
wheel_width            = 26;   // spec do kit
motor_x_position         = -100.05; // REAL (STL de referência)
motor_y_offset            = 50.4;    // REAL (média dos dois furos em cruz, ±48.53/±52.26)

// --- Motores DC (70x37x23) — os recortes em cruz já existem na peça real,
// não precisam ser cortados por este modelo; só usamos o footprint p/ o
// preview 3D do motor+suporte. ---
motor_footprint           = [70, 37, 23];

// --- KL25Z (reaproveita os STLs existentes) — posicionado na área aberta
// do corpo principal da chapa (nariz, sem flare, oposto aos motores). ---
kl25z_footprint             = [53.34, 81.28];
kl25z_position                = [35, 0];
kl25z_rotation                 = 0;
kl25z_drilling_guide_stl        = "../assets/freescale_kl25z_drilling_guide.stl";
kl25z_mounting_plate_stl        = "../assets/freescale_kl25z_mounting_plate.stl";

// --- HW-201 (par, um por roda, medindo disco de marcação) ---
hw201_footprint                = [10, 32];  // ASSUNÇÃO
hw201_hole_d                    = 2.5;
hw201_x_offset_from_motor         = 22;     // desloca o sensor do motor em direção ao corpo (x = motor_x + offset)

// --- HC-SR04 (padrão de furação confirmado no datasheet do repo) ---
hcsr04_hole_spacing              = 16;
hcsr04_footprint                   = [45, 20];
hcsr04_hole_d                       = 2.5;
hcsr04_position                       = [80, 0]; // ponta do nariz (extremidade sem flare), sensor voltado p/ frente

// --- Driver ponte H (já fixado no chassi real — ASSUNÇÃO tipo L298N) ---
driver_footprint                    = [43, 43];
driver_height                        = 15;   // ASSUNÇÃO
driver_hole_inset                     = 3;
driver_position                        = [-32, 0];

// --- Roda caster ---
// O furo real (redondo, Ø≈19.5mm, x=-91.3 y=0, bem à frente dos motores)
// já existe na peça — não precisamos cortar nada, só desenhar o preview 3D.
caster_position                            = [-91.3, 0]; // REAL (STL de referência)
caster_diameter                             = 19.5;       // REAL
caster_height                                = 25;         // ASSUNÇÃO, p/ preview

// --- Baterias 9V (2 ou 3, opcionais — potência extra dos motores) ---
// Deitadas (comprimento na horizontal) para minimizar altura sobre a chapa.
battery9v_count                             = 2;    // 2 ou 3, ajustável
battery9v_body_footprint                     = [48.5, 26.5, 17.5]; // NEDA 1604/IEC 6LR61, deitada
battery9v_spacing                             = 30;  // entre eixos, ao longo de Y
battery9v_position                             = [-55, 15];

// --- Powerbank 5V (lógica) ---
// Sem cutout na chapa: fica sobre o andar superior (deck da PCB), preso por
// velcro — mais tolerante à falta de modelo definido e evita competir por
// espaço na chapa já congestionada.
powerbank_footprint                             = [100, 35, 15]; // ASSUNÇÃO, ajustar ao modelo escolhido
powerbank_mount_style                            = "velcro_on_deck";
powerbank_deck_offset                             = [0, 40]; // posição sobre o deck, relativa ao centro da PCB

// --- PCB própria (10x10cm, pedido do usuário) ---
// Fica em um andar superior sobre espaçadores impressos, acima de todos os
// componentes da chapa base (a bateria 9V deitada é o item mais alto, 17.5mm).
pcb_footprint                                     = [100, 100];
pcb_thickness                                      = 1.6;   // espessura padrão de PCB
pcb_hole_d                                          = 3;
pcb_standoff_footprint                               = [90, 70]; // onde os 4 pés pousam na chapa
pcb_hole_inset                                        = 8;
pcb_standoff_height                                    = 30;  // > altura da bateria 9V deitada (17.5mm) + folga
pcb_position                                            = [-10, 0]; // centralizado sobre motores/driver/baterias
pcb_on_upper_level                                       = true;

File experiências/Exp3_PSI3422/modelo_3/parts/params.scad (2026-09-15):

include <BOSL2/std.scad>

$fs = 0.5;
$fa = 2;

// ============================================================
// PARÂMETROS — modelo_3
//
// Mudança de abordagem em relação a modelo_1/2: a chapa é importada
// como SÓLIDO 3D real (assets/2wd_robot/chassis_plate.stl), sem
// achatar via projection()+linear_extrude e sem nenhuma rotação —
// usamos o referencial NATIVO do arquivo original (mesmo referencial
// do .blend baixado pelo usuário), para eliminar qualquer erro de
// transformação manual. Isso inverte length/width em relação a
// modelo_1/2:
//   X = largura do chassi (eixo lateral, ~149mm de ponta a ponta)
//   Y = comprimento do chassi / sentido de deslocamento (~210mm)
//   Z = altura (para cima)
//
// A posição dos motores e do rodízio vem de consulta direta ao
// .blend (bpy matrix_world.translation dos objetos "Motor",
// "Motor.001" e "Caster") — não são mais inferidas a partir de furos
// da chapa (essa inferência anterior, usada em modelo_1/2, estava
// desalinhada com a peça real, ver conversa).
// ============================================================

chassis_ref_stl       = "../assets/2wd_robot/chassis_plate.stl";

// --- Chapa: geometria real ---
// A chapa em si é fina (3mm, medido no histograma de vértices do STL:
// concentração maciça em Z=45 e Z=48, o resto são uns poucos pinos de
// alinhamento saindo dela) apesar da bounding box total (21.12-54.10)
// sugerir 33mm — isso é só a extensão desses pinos, não a chapa.
plate_top_z            = 48;    // REAL — superfície de cima da chapa
plate_bottom_z          = 45;    // REAL — superfície de baixo da chapa
plate_bbox_x            = [-76.36, 72.62];  // REAL, largura (X)
plate_bbox_y             = [-120.28, 89.69]; // REAL, comprimento (Y)

// --- Motores + rodas (posição REAL, lida do .blend) ---
// Os objetos "Motor"/"Motor.001" do .blend já incluem motor+roda como
// um único mesh (o Z bate exatamente com o diâmetro da roda). Usamos
// só a bounding box real deles para posicionar um cilindro (roda) +
// caixa (corpo do motor) simplificados — miniatura fiel o bastante,
// sem precisar importar os 16MB de cada malha real.
motor_l_center          = [-51.03, -32.97, 34.93]; // REAL (Motor)
motor_r_center           = [47.52, -32.97, 34.93]; // REAL (Motor.001)
motor_wheel_diameter      = 68.92; // REAL — bate com o Z-span do mesh (roda toca o chão em Z≈0.47)
motor_wheel_width          = 26;    // ASSUNÇÃO (largura da roda, não dá pra isolar do mesh combinado)
motor_body_footprint        = [37, 70, 23]; // ASSUNÇÃO (corpo do motor TT, X x Y x Z)

// --- Rodízio (posição REAL, lida do .blend) ---
caster_center             = [-2.00, 79.21, 25.77]; // REAL (objeto "Caster")
caster_footprint            = [38.00, 46.49, 39.98]; // REAL (dimensions do objeto)

// --- Ponte H L298N (embaixo da chapa) ---
l298n_footprint               = [43, 43, 26]; // spec típica do módulo L298N (incl. dissipador)
l298n_hole_inset                = 3;
l298n_position                    = [0, 10]; // área central aberta da chapa

// --- Sensor ultrassônico HC-SR04 ---
// CORRIGIDO no modelo_3: a maior dimensão (45mm) fica PERPENDICULAR
// ao sentido de deslocamento (Y) — ou seja, ao longo de X — e não mais
// alinhada com Y como em modelo_1/2. Fica na frente (Y alto, perto do
// rodízio) e voltado pra frente (+Y).
hcsr04_footprint_xy               = [45, 20]; // [X, Y] — 45 ao longo de X (perpendicular ao deslocamento)
hcsr04_hole_spacing                = 16;       // ao longo de X, mesmo eixo da maior dimensão
hcsr04_hole_d                       = 2.5;
hcsr04_height                        = 20;
hcsr04_position                       = [0, 78]; // entre a borda da PCB (y~30) e o rodízio (y~56) — frente da chapa

// --- FRDM-KL25Z ---
// Montada ACIMA do shield de PCB (não mais direto na chapa) — ver
// pcb_kl25z_gap abaixo.
kl25z_footprint                        = [53.34, 81.28];
kl25z_rotation                          = 0;
kl25z_drilling_guide_stl                 = "../assets/freescale_kl25z_drilling_guide.stl";
kl25z_mounting_plate_stl                  = "../assets/freescale_kl25z_mounting_plate.stl";

// --- PCB própria (shield, 10x10cm) ---
// Andar 1 (acima da chapa): PCB shield, sustentada por 4 pés impressos.
// Andar 2 (acima do shield): FRDM-KL25Z, empilhada por cima como um
// shield de Arduino.
pcb_footprint                            = [100, 100];
pcb_thickness                             = 1.6;
pcb_hole_d                                 = 3;
pcb_standoff_footprint                      = [90, 70]; // onde os 4 pés pousam na chapa
pcb_hole_inset                               = 8;
pcb_standoff_height                           = 30;  // chapa -> shield (folga da ponte H, que fica embaixo, e do L298N não interfere pq está embaixo tb)
pcb_position                                   = [0, -5]; // recuada p/ abrir espaço ao HC-SR04 na frente (ver hcsr04_position)
kl25z_standoff_height                           = 12;  // shield -> KL25Z (pequeno, tipo pino de shield)
kl25z_position_on_pcb                            = [0, 0]; // relativo ao centro da PCB

// --- HW-201 (par, um por roda) ---
// Cada um fica perto do respectivo motor/roda e aponta pra ela — a
// roda gira em torno do eixo X (perpendicular ao deslocamento Y), suas
// faces ficam voltadas para ±X, então o sensor "olha" ao longo de X.
hw201_footprint                                  = [10, 32]; // [ao longo de Y, altura]
hw201_hole_d                                      = 2.5;
hw201_y_offset_from_motor                          = 15; // desloca o sensor do motor em direção ao corpo (y = motor_y - offset)

// --- Módulo nRF24L01+ ---
// Encaixe simples (bolso de 3 paredes impresso) pra não ficar solto —
// só precisa posicionar a caixinha corretamente, sem parafusos.
nrf24_footprint                                     = [30.3, 14.5, 8]; // spec do módulo padrão c/ antena PCB
nrf24_pocket_wall                                     = 1.6;
nrf24_position_on_pcb                                  = [-30, 35]; // canto da PCB shield, relativo ao seu centro

// --- Baterias 9V (bocais/suportes, opcional — potência extra dos motores) ---
// Dimensão do SUPORTE completo (com tampa, sem plug — só a caixa),
// pesquisada em lojas de robótica BR: ~55x31x20mm por unidade.
battery9v_count                                        = 2;
battery9v_holder_footprint                              = [55, 31, 20]; // [X, Y, Z]
battery9v_spacing                                        = 35; // entre eixos, ao longo de X
battery9v_position                                        = [0, -75]; // área aberta atrás dos motores

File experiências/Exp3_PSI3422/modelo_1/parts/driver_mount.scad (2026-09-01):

include <params.scad>

module driver_mount_cutout() {
    translate(driver_position)
        for (sx = [-1, 1])
            for (sy = [-1, 1])
                translate([
                    sx * (driver_footprint[0] / 2 - driver_hole_inset),
                    sy * (driver_footprint[1] / 2 - driver_hole_inset)
                ])
                    circle(d = 3.2);
}

module driver_preview() {
    color("SteelBlue", 0.5)
        translate([driver_position[0], driver_position[1], driver_height / 2])
            cube([driver_footprint[0], driver_footprint[1], driver_height], center = true);
}

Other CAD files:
experiências/Exp3_PSI3422/assets/2wd_robot/motor_l.stl
experiências/Exp3_PSI3422/docs/aprendendo_openscad.scad
experiências/Exp3_PSI3422/modelo_1/chassi.scad
experiências/Exp3_PSI3422/modelo_1/parts/base_plate.scad
experiências/Exp3_PSI3422/modelo_1/parts/battery_holder.scad
experiências/Exp3_PSI3422/modelo_1/parts/caster_mount.scad
experiências/Exp3_PSI3422/modelo_1/parts/hcsr04_mount.scad
experiências/Exp3_PSI3422/modelo_1/parts/hw201_mount.scad
experiências/Exp3_PSI3422/modelo_1/parts/kl25z_mount.scad
experiências/Exp3_PSI3422/modelo_1/parts/motor_mount.scad
experiências/Exp3_PSI3422/modelo_1/parts/pcb_mount.scad
experiências/Exp3_PSI3422/modelo_1/parts/powerbank_mount.scad
experiências/Exp3_PSI3422/modelo_1/print/battery9v_cradle.scad
experiências/Exp3_PSI3422/modelo_1/print/hw201_bracket.scad
experiências/Exp3_PSI3422/modelo_1/print/pcb_standoff.scad
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

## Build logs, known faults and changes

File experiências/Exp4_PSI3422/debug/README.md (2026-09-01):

# debug/ — validações de bancada, fora da entrega

Firmwares isolados pra validar hardware sem depender do resto do
Exp4_PSI3422 — se algo não bate aqui, o problema é do sensor/fiação,
não da lib compartilhada (`../../../lib/encoder`,
`../../../lib/odometria`).

## IRHW201_ESP32

Flasha numa ESP32 avulsa (`upesy_wroom`) numa protoboard — não no
board do CarrinhoBase (KL25Z). Serial monitor: **115200 8N1**
(`monitor_speed` já no `platformio.ini`).

Objetivo não é medir PPS com motor girando (isso já foi validado em
`../../Exp2_PSI3422/debug/EncoderCheck`); é caracterizar o sensor
HW-201 isolado, na mão, antes de confiar no `GPIO_INT_EDGE_RISING`
assumido em `../../../lib/encoder/encoder.h`:

- nível de repouso do `OUT` com o feixe livre;
- qual borda (subida ou descida) corresponde a "feixe interrompido";
- se o sinal é limpo (sem bouncing) ao interromper o feixe manualmente
  (cartão/dedo no gap do sensor).

Fiação (HW-201, 3 pinos):

| HW-201 | ESP32 |
|---|---|
| VCC | 3V3 (**não** 5V — GPIO da ESP32 não é tolerante a 5V) |
| GND | GND |
| OUT | GPIO4 |

Rodar: `pio run -t upload -t monitor` dentro de `IRHW201_ESP32/`.

**Resultado confirmado em bancada** (protoboard, ESP32 + HW-201,
2026-09-01): `HIGH` = feixe livre, `LOW` = feixe interrompido. A
transição que marca "acabou de bloquear" é `FALLING`; a marca
"acabou de liberar" é `RISING`.

Saída de exemplo (feixe livre, depois interrompido à mão):

```
=== IRHW201_ESP32 -- debug de bancada do sensor IR HW-201 ===
Nivel de repouso (feixe livre) em GPIO4: HIGH
Interrompa o feixe com a mao/cartao e veja qual contagem sobe.
'intervalo_min' baixo (poucos us) e repetido = sinal de bouncing.

nivel=HIGH  subidas/s=  0  descidas/s=  0  intervalo_min=0 us
nivel=HIGH  subidas/s=  3  descidas/s=  3  intervalo_min=41207 us
nivel=HIGH  subidas/s=  0  descidas/s=  0  intervalo_min=0 us
```

Como ler:
- `subidas/s` e `descidas/s` sempre variam juntos (cada interrupção
  do feixe gera uma borda de cada tipo) — cada bloqueio soma 1 em
  ambos, então a contagem por segundo em si não é afetada pela
  polaridade.
- `intervalo_min` na casa de poucas centenas de µs, repetindo a cada
  interrupção manual do feixe, indicaria bouncing — não observado
  nesta bancada.
- Se `subidas/s`/`descidas/s` ficarem em 0 mesmo interrompendo o
  feixe, ajuste o trimpot do módulo até o LED dele reagir; se nada
  mudar, é falha do módulo, não do firmware.

**Sobre `lib/encoder/encoder.h`:** o código lá usa
`GPIO_INT_EDGE_RISING` — como cada bloqueio do feixe gera exatamente
uma borda de subida e uma de descida (mesma contagem por revolução
nos dois casos), a polaridade *não* muda quantos pulsos são contados,
só a fase (se o pulso é contado no instante em que bloqueia ou no
instante em que libera). Não é necessário alterar o código por causa
deste resultado — troca só faria sentido se algum dia a lib precisar
disparar exatamente no instante do bloqueio (ex.: medir duração do
bloqueio), o que a Aula 4 não pede.

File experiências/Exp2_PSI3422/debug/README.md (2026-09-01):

# debug/ — validações de bancada, fora da entrega

Firmwares Zephyr isolados pra validar hardware sem depender do resto
do Exp2_PSI3422 (rádio, control_fsm, etc.) — se algo não bate aqui, o
problema é de fiação/mecânica, não de lógica de controle. Vivem na
branch `debug/exp2-validacoes`, não em `main`.

Serial monitor: **115200 8N1**, não 9600 — `current-speed` no
`zephyr.dts` gerado pelo build (Carrinho, Controle e os três
firmwares daqui) é sempre `0x1c200` = 115200; `pio device monitor`
sem `--baud` já cai nesse default do board.

## monitor.py

Painel serial (`uv run monitor.py [porta] [--control]`) que lê a
saída de qualquer um dos firmwares (Carrinho, Controle, JoystickCheck,
AlinhamentoCheck), separa os tipos de log em métricas ao vivo
(telemetria, comando, joystick bruto, fase do AlinhamentoCheck,
erros/avisos) e, com `--control`, repassa w/a/s/d/x/espaço/q/o pra
UART do Controle — mesmo protocolo de
`../Controle/script/controle_serial.py`. Ver docstring do script pra
detalhes. As linhas `SWEEP ...` do DutySweepCheck ainda não têm painel
dedicado, caem no log bruto.

## JoystickCheck

Flasha no board do **Controle**. Lê X/Y do joystick (ADC) e o botão
de freio a cada 200ms e imprime bruto + o `motor_l`/`motor_r` que
`../Controle/src/main.c` derivaria.

Usa isso pra confirmar que o eixo não está preso em 3,3V/4095 (defeito
já visto nesta bancada, ver aviso em `../Controle/src/main.c`) antes
de confiar no joystick pra controlar o carrinho de verdade.

## AlinhamentoCheck

Flasha no board do **Carrinho**. Só motor + PWM (sem ultrassom, sem
rádio, sem control_fsm): manda o mesmo duty fixo (~50%) pros dois
motores por 3s, freia, pausa 2s, repete indefinidamente. Coloque o
carrinho no chão e observe se ele desvia pra um lado.

Como os dois motores recebem literalmente o mesmo valor, qualquer
desvio observado aqui é mecânico (roda torta, folga, atrito
desigual) — não dá pra atribuir a uma diferença de código entre os
dois lados.

## DutySweepCheck

Flasha no board do **Carrinho**. Testado depois do `AlinhamentoCheck`
mostrar o carrinho andando torto: sobe o duty de CADA motor sozinho
(o outro freado) em degraus de 0 até o máximo, ~1,5s por degrau, e
imprime o duty a cada passo. Levante o carrinho do chão e anote o
duty onde cada roda sai do lugar (torque de arranque) — se os dois
valores forem bem diferentes, é evidência objetiva de motor/ponte
H/fiação desigual, não só impressão visual.

Conferido antes de suspeitar de hardware: `pwm_z42.c`/`motor.c`
escrevem `CnV`/`CnSC` pelo mesmo código pros dois canais TPM, só
endereçando índices diferentes — duty comandado é garantidamente
idêntico em registrador nos dois motores.

## EncoderCheck

Flasha no board do **Carrinho**. Mesmo duty fixo nos dois motores
(igual `AlinhamentoCheck`), mas agora conta pulsos dos dois encoders
IR HW-201 (um por roda) e imprime pulsos/segundo (PPS) de cada lado a
cada 1s — dá um número real de rotação em vez de só observação
visual. Levante o carrinho do chão antes de ligar.

Encoders ainda não instalados fisicamente — pinos reservados em
PTD1 (esquerda) / PTD3 (direita), ver `../Pinmap.md`. De propósito
NÃO em PORTB/PORTE: nesta subfamília KL25Z só PORTA e PORTC/PORTD têm
vetor de interrupção de pino — foi exatamente o problema relatado ao
tentar usar `gpioe` como IRQ antes.

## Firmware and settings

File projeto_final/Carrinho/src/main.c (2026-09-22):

/*
 * PSI3422 — projeto_final / Carrinho
 *
 * Consolidação de produção: 2 motores DC (ponte H dupla) + ultrassom
 * HC-SR04 + rádio nRF24L01+ (base: experiências/Exp2_PSI3422/Carrinho)
 * com encoder IR HW-201 + odometria somados por cima (base:
 * experiências/Exp4_PSI3422/CarrinhoBase) — cobre o roteiro das
 * Aulas 5/6 (README.md raiz): RUN/STOP remotos, travessia de
 * labirinto por desvio reativo, distância percorrida que nunca
 * decresce, comando de apagar. Board: FRDM-KL25Z.
 *
 * Só ENCODER_R está no pinmap atual (ver ../../pinmap.yaml) — o
 * carrinho não tem mais o encoder esquerdo fisicamente montado.
 * lib/odometria continua a mesma (odometria diferencial, dois
 * deltas) — sem modificar o contrato dela (ver lib/SPEC.md), o delta
 * da roda direita é passado pros dois parâmetros, assumindo as rodas
 * andando junto (mesmo PWM nos dois motores fora de curva). Efeito:
 * `pose.theta_rad` fica sempre 0 (d_dir - d_esq cancela) — não tem
 * problema porque nada usa esse campo hoje (só
 * `distancia_percorrida_m` vai pra telemetria); `distancia_percorrida_m`
 * continua correta porque colapsa pra |d_dir| quando os dois deltas
 * são iguais.
 *
 * Pinos: ver ../../pinmap.h (gerado por ../../tools/gen_pinmap.py a
 * partir de ../../pinmap.yaml). RADIO_SCK/MOSI/MISO do módulo nRF24
 * foram movidos pra PTC5/PTC6/PTC7 em 22/09/2026 (nrf24_read_status()
 * mostrava 0xFF travado com o módulo em PTD6/PTB9/PTD7 — SPI0 de
 * hardware só existe em PORTC/PORTA nesta família de chip, nunca
 * poderia alcançar PTD6/PTB9/PTD7; ver ../../pinmap_carrinho.yaml
 * pro registro histórico do que a PCB tinha antes do rework).
 * Protocolo de rádio: ../../protocol.h.
 *
 * ── Arquitetura híbrida (GPIO Zephyr nativo, PWM/SPI bare-metal) e
 * por que um laço síncrono só (sem thread de rádio dedicada) ──
 * ver o comentário equivalente, mais longo, em
 * experiências/Exp2_PSI3422/Carrinho/src/main.c — inalterado aqui,
 * não repetido pra não desincronizar duas cópias do mesmo racional.
 *
 * RUN = auto_mode (desvio reativo por ultrassom frontal, 4 faixas —
 * ver lib/control_fsm/control_fsm.c). É a "travessia de labirinto"
 * cabível aqui: o carrinho só tem um sensor de distância (frontal),
 * não há como mapear o labirinto, só reagir ao obstáculo mais
 * próximo. Herdado de Exp2_PSI3422 sem mudança de lógica — por
 * PENDENCIAS.md daquele experimento, essa lógica nunca rodou em
 * carrinho de verdade, só buildou; validação de bancada fica pra
 * quando o hardware estiver montado.
 * STOP = freio (motores ignorados, carrinho parado).
 */

#include <zephyr.h>
#include <device.h>
#include <drivers/gpio.h>
#include <sys/printk.h>

#include "pwm_z42.h"
#include "motor.h"
#include "ultrassom.h"
#include "encoder.h"
#include "odometria.h"
#include "nrf24.h"
#include "control_fsm.h"
#include "../../protocol.h"
#include "../../pinmap.h"

/* TPM0 compartilhado pelos 2 canais de PWM dos motores: MCGIRCLK (4MHz,
 * independente do PLL) / PS_1 -> f_tpm = 4MHz; MOD=3999 -> f_pwm = 1kHz
 * (audível mas comum e seguro para motor DC via L298N). */
#define TPM_MOTOR_MOD 3999U

/* ── Calibração da odometria — medida em bancada, ver
 * ../README.md ("Parâmetros do carrinho": 17cm entre rodas, roda de
 * raio 3,5cm — este último bate com motor_wheel_diameter=68,92mm em
 * experiências/Exp3_PSI3422/modelo_3/parts/params.scad, medido do
 * .blend). Substitui os valores antigos (20cm/5cm) herdados de
 * experiências/Exp4_PSI3422/CarrinhoBase/src/main.c, que eram
 * estimativa, não medição do chassi real. pulsos/volta=1 (marco de
 * papel na roda) continua a confirmar girando N voltas em bancada —
 * ver control/relatorio-aula-4.md. ── */
#define DISTANCIA_ENTRE_RODAS_M 0.17f
#define PULSOS_POR_VOLTA 1
#define RODA_RAIO_M 0.035f
#define RODA_CIRCUNFERENCIA_M (2.0f * 3.14159265f * RODA_RAIO_M)

static motor_t motor_l;
static motor_t motor_r;
static ultrassom_t sensor;
static encoder_t encoder_r;
static odometria_pose_t pose;

void main()
{
    struct gpio_dt_spec l_in1 = { .port = MOTOR_L_IN1_PORT, .pin = MOTOR_L_IN1_PIN, .dt_flags = GPIO_ACTIVE_HIGH };
    struct gpio_dt_spec l_in2 = { .port = MOTOR_L_IN1_PORT, .pin = MOTOR_L_IN2_PIN, .dt_flags = GPIO_ACTIVE_HIGH };
    struct gpio_dt_spec r_in1 = { .port = MOTOR_R_IN1_PORT, .pin = MOTOR_R_IN1_PIN, .dt_flags = GPIO_ACTIVE_HIGH };
    struct gpio_dt_spec r_in2 = { .port = MOTOR_R_IN2_PORT, .pin = MOTOR_R_IN2_PIN, .dt_flags = GPIO_ACTIVE_HIGH };
    struct gpio_dt_spec trig  = { .port = ULTRASSOM_TRIG_PORT, .pin = ULTRASSOM_TRIG_PIN, .dt_flags = GPIO_ACTIVE_HIGH };
    struct gpio_dt_spec echo  = { .port = ULTRASSOM_ECHO_PORT, .pin = ULTRASSOM_ECHO_PIN, .dt_flags = GPIO_ACTIVE_HIGH };
    struct gpio_dt_spec enc_r = { .port = ENCODER_R_PORT, .pin = ENCODER_R_PIN, .dt_flags = GPIO_ACTIVE_HIGH };
    struct gpio_dt_spec ce    = { .port = RADIO_CE_PORT, .pin = RADIO_CE_PIN, .dt_flags = GPIO_ACTIVE_HIGH };
    struct gpio_dt_spec csn   = { .port = RADIO_CSN_PORT, .pin = RADIO_CSN_PIN, .dt_flags = GPIO_ACTIVE_LOW };
    struct gpio_dt_spec irq   = { .port = RADIO_IRQ_PORT, .pin = RADIO_IRQ_PIN, .dt_flags = GPIO_ACTIVE_LOW };

    struct gpio_dt_spec led_red = { .port = LED_RED_PORT, .pin = LED_RED_PIN, .dt_flags = GPIO_ACTIVE_LOW };
    struct gpio_dt_spec led_green = { .port = LED_GREEN_PORT, .pin = LED_GREEN_PIN, .dt_flags = GPIO_ACTIVE_LOW };
    if (device_is_ready(led_red.port)) {
        gpio_pin_configure_dt(&led_red, GPIO_OUTPUT_INACTIVE);
        gpio_pin_configure_dt(&led_green, GPIO_OUTPUT_INACTIVE);
    }
    int ret;

    /* TPM0 uma vez só — MOD (período) é compartilhado por todos os canais */
    if (!pwm_tpm_Init(TPM0, TPM_MCGIRCLK, TPM_MOTOR_MOD, TPM_CLK, PS_1, EDGE_PWM)) {
        printk("ERRO: pwm_tpm_Init(TPM0) falhou\n");
        return;
    }
    if (!pwm_tpm_Ch_Init(TPM0, MOTOR_L_ENA_CH, TPM_PWM_H, MOTOR_L_ENA_GPIO, MOTOR_L_ENA_PIN)) {
        printk("ERRO: pwm_tpm_Ch_Init(motor L) falhou\n");
        return;
    }
    if (!pwm_tpm_Ch_Init(TPM0, MOTOR_R_ENB_CH, TPM_PWM_H, MOTOR_R_ENB_GPIO, MOTOR_R_ENB_PIN)) {
        printk("ERRO: pwm_tpm_Ch_Init(motor R) falhou\n");
        return;
    }

    ret = motor_init(&motor_l, &l_in1, &l_in2, TPM0, MOTOR_L_ENA_CH, TPM_MOTOR_MOD);
    if (ret < 0) { printk("ERRO: motor_init(L) = %d\n", ret); return; }

    /* r_in2/r_in1 invertidos (não r_in1/r_in2): motor R girava ao
     * contrário do esperado em bancada — fix de orientação validado
     * em debug_projeto_final ("orientar rodas"), propagado aqui. */
    ret = motor_init(&motor_r, &r_in2, &r_in1, TPM0, MOTOR_R_ENB_CH, TPM_MOTOR_MOD);
    if (ret < 0) { printk("ERRO: motor_init(R) = %d\n", ret); return; }

    ret = ultrassom_init(&sensor, &trig, &echo);
    if (ret < 0) { printk("ERRO: ultrassom_init = %d\n", ret); return; }

    /* encoder_init depois de motor_init: a ISR do encoder lê motor->speed,
     * então o motor associado precisa já existir (não precisa girar ainda).
     * Só ENCODER_R existe fisicamente (ver comentário no topo do arquivo). */
    ret = encoder_init(&encoder_r, &enc_r, &motor_r);
    if (ret < 0) { printk("ERRO: encoder_init(R) = %d\n", ret); return; }

    odometria_calibracao_t odo_calib = {
        .circunferencia_roda_m = RODA_CIRCUNFERENCIA_M,
        .distancia_entre_rodas_m = DISTANCIA_ENTRE_RODAS_M,
        .pulsos_por_volta = PULSOS_POR_VOLTA,
    };
    odometria_init(&pose);

    printk("\n==================================\n");
    printk("=== BOOTING CARRINHO APP       ===\n");
    printk("==================================\n");

    ret = nrf24_init(&ce, &csn, &irq);
    if (ret < 0) {
        printk("ERRO: rádio falhou = %d. Carrinho continuará sem rádio.\n", ret);
    }

    printk("PSI3422 projeto_final — carrinho pronto\n");

    radio_cmd_t cmd = { .auto_mode = 1 }; /* começa em RUN (modo seguro: desvia sozinho) */
    uint8_t last_apagar_seq = 0;
    control_fsm_heartbeat();

    for (;;) {
        /*
         * O rádio é configurado (nrf24_init) com payload fixo de
         * NRF24_MAX_PAYLOAD_SIZE (32) nos dois lados — nrf24_receive()
         * exige um buffer de pelo menos esse tamanho e sempre lê os
         * 32 bytes inteiros, então o buffer de rádio continua sendo
         * uint8_t[32]; radio_cmd_t/radio_telemetry_t (protocol.h) só
         * descrevem os bytes que de fato importam no início dele.
         */
        uint8_t rx_payload[NRF24_MAX_PAYLOAD_SIZE];
        uint8_t tx_payload[NRF24_MAX_PAYLOAD_SIZE] = {0};

        ret = nrf24_receive(rx_payload, sizeof(rx_payload), K_MSEC(100));
        if (ret >= 0) {
            cmd = *(const radio_cmd_t *)rx_payload;
            control_fsm_heartbeat();

            static int rx_cnt = 0;
            if (++rx_cnt % 10 == 0) {
                printk("-> recebido: auto=%d freio=%d motL=%d motR=%d\n", cmd.auto_mode, cmd.freio, cmd.motor_l, cmd.motor_r);
            }
        }

        /* ── Controle dos LEDs de Status ── */
        /* O watchdog retorna true se não tiver controle (timeout) */
        bool sem_radio = control_fsm_watchdog(&cmd); /* sem comando há > 500ms -> força RUN (auto_mode) */
        gpio_pin_set_dt(&led_red, sem_radio ? 1 : 0);
        gpio_pin_set_dt(&led_green, sem_radio ? 0 : 1);

        // Se ficar 2 segundos sem rádio (após handshake), tenta reiniciar o módulo
        static int64_t radio_lost_time = 0;
        static bool handshake = false;

        if (!sem_radio) {
            handshake = true;
            radio_lost_time = 0;
        } else if (handshake) {
            if (radio_lost_time == 0) {
                radio_lost_time = k_uptime_get();
            } else if (k_uptime_get() - radio_lost_time > 2000) {
                printk("Reconectando modulo NRF24 do Carrinho...\n");
                nrf24_init(&ce, &csn, &irq);
                radio_lost_time = k_uptime_get(); // Tenta de novo em 2s
            }
        }

        /* ── Atualizar Sensor Ultrassom ── */
        ultrassom_read(&sensor); // Atualiza sensor->distance

        control_fsm_apply(&cmd, &motor_l, &motor_r, &sensor);

        /* ── Odometria: delta de pulsos desde o último ciclo (~50ms) ──
         * Só ENCODER_R existe fisicamente: o delta dele é passado pros
         * dois parâmetros de odometria_atualiza (ver comentário no topo
         * do arquivo — theta_rad fica sempre 0, distancia_percorrida_m
         * continua correta). */
        int32_t delta_r = encoder_reset(&encoder_r);
        odometria_atualiza(&pose, &odo_calib, delta_r, delta_r);

        /* "Apagar distância": borda de apagar_seq (não nível) — ver
         * comentário em protocol.h sobre por que é contador, não flag. */
        if (cmd.apagar_seq != last_apagar_seq) {
            last_apagar_seq = cmd.apagar_seq;
            odometria_init(&pose);
            printk("Distancia percorrida apagada (comando remoto).\n");
        }

        uint16_t dist = (uint16_t)(sensor.distance * 100.0f);
        int16_t out_l = (int16_t)(motor_get_duty(&motor_l) * 1000.0f);
        int16_t out_r = (int16_t)(motor_get_duty(&motor_r) * 1000.0f);
        uint32_t dist_percorrida_cm = (uint32_t)(pose.distancia_percorrida_m * 100.0f);

        *(radio_telemetry_t *)tx_payload = (radio_telemetry_t){
            .dist_cm = dist, .duty_l = out_l, .duty_r = out_r,
            .dist_percorrida_cm = dist_percorrida_cm,
        };
        nrf24_send(tx_payload, sizeof(tx_payload));

        static int loop_cnt = 0;
        if (++loop_cnt % 10 == 0) { // roughly every 500ms
            printk("car heartbeat: dist=%dcm cmd.auto=%d outL=%d outR=%d percorrida=%ucm (sem_radio=%d)\n",
                   dist, cmd.auto_mode, out_l, out_r, dist_percorrida_cm, sem_radio);
        }

        k_msleep(50);
    }
}

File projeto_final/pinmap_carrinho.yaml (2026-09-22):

# Pinmap do Carrinho FÍSICO (PCB já fabricada) — bifurcado de
# pinmap.yaml em 2026-09-22. pinmap.yaml (a fonte "atual") passou a
# valer só pro Controle, que foi fiado à mão DEPOIS do fix de
# RADIO_SCK/MOSI/MISO (PTC5/PTC6/PTC7); a PCB do Carrinho já existia
# antes disso e foi roteada em cima do pinmap.yaml de antes do fix —
# commit 6e70945 (RADIO_SCK/MOSI/MISO = PTD6/PTB9/PTD7).
#
# NÃO inclui o revert do fix de canal TPM dos motores
# (MOTOR_L_ENA_CH/MOTOR_R_ENB_CH): esse bug não é diferença de PCB —
# é o próprio silício da KL25Z (PTD2 é sempre TPM0_CH2, PTA4 é sempre
# TPM0_CH1, confirmado em MKL25Z128VLK4-pinctrl.dtsi,
# independentemente de qual PCB está plugada) — reverter isso
# reintroduziria um bug real. Só RADIO_SCK/MOSI/MISO voltou pro valor
# de 6e70945 aqui.
#
# ATENÇÃO: PTD6/PTB9/PTD7 não são rota de hardware do SPI0 nem SPI1
# na KL25Z (só PORTC/PORTA pro SPI0 — ver lib/spi/spi.c) — se a PCB
# do Carrinho really tem o nRF24 fiado nesses pinos, nrf24_init()
# (que chama spi_init(SPI_0, ALT_0, ...), fixo em PTC5/PTC6/PTC7) NÃO
# consegue falar com o rádio da PCB por hardware SPI0. Ou o SPI
# precisa ser bit-banged nesses 3 pinos especificamente pro Carrinho,
# ou a fiação física do módulo na PCB precisa ser conferida antes de
# assumir que é isso — ainda não decidido, ver
# projeto_final/README.md.
#
# NÃO EDITAR os arquivos gerados a partir daqui (pinmap_carrinho.h,
# Pinmap_carrinho.md, kicad/PSI3422_shield_carrinho.kicad_sym) —
# editar este YAML e rodar
# `python3 tools/gen_pinmap.py pinmap_carrinho.yaml` de dentro de
# projeto_final/.
#
# Campos de cada pino:
#   nome     : usado pra gerar o(s) #define em pinmap.h (MAIÚSCULO)
#   porta    : letra do PORT da KL25Z (A-E)
#   pino     : número do pino dentro do port (PTxN)
#   tipo     : gpio | pwm | adc | doc
#     gpio -> pinmap.h ganha <nome>_PORT (DEVICE_DT_GET(DT_NODELABEL(gpio<porta>)))
#             e <nome>_PIN (número) — cobre entrada, saída e entrada com IRQ,
#             a diferença fica só no `obs`/`direcao`, não no define.
#     pwm  -> pino de velocidade dos motores, controlado via lib/pwm_z42
#             (bare-metal, não passa por devicetree): pinmap.h ganha
#             <nome>_GPIO (GPIO<porta>, macro CMSIS), <nome>_PIN e
#             <nome>_CH (canal TPM, campo canal_tpm obrigatório).
#     adc  -> canal ADC0 (joystick): pinmap.h ganha só <nome>_CHANNEL
#             (campo canal_adc obrigatório) — porta/pino ficam só como
#             documentação (Pinmap.md/kicad), o código usa o canal.
#     doc  -> informativo apenas (ex.: SPI/UART fixos internamente por
#             lib/spi ou pela devicetree) — não gera define nenhum.
#   direcao  : saida | entrada | entrada_irq | pwm | adc | fixo
#   boards   : lista com "carrinho" e/ou "controle"
#   canal_tpm: canal do TPM0 (só tipo=pwm)
#   canal_adc: canal do ADC0 (só tipo=adc)
#   obs      : nota curta (motivo da escolha, referência a debug/lib)

pins:
  # ── Motores (só Carrinho) ────────────────────────────────────────
  - nome: MOTOR_L_IN1
    porta: D
    pino: 0
    tipo: gpio
    direcao: saida
    boards: [carrinho]
    obs: Ponte H, direção do motor esquerdo (lib/motor)
  - nome: MOTOR_L_IN2
    porta: C
    pino: 9
    tipo: gpio
    direcao: saida
    boards: [carrinho]
    obs: Ponte H, direção do motor esquerdo (lib/motor)
  - nome: MOTOR_L_ENA
    porta: D
    pino: 2
    tipo: pwm
    direcao: pwm
    canal_tpm: 2
    boards: [carrinho]
    obs: TPM0_CH2, velocidade do motor esquerdo, via lib/pwm_z42 (canal corrigido — ver debug/debug_ponte_H_encoder/src/main.c)
  - nome: MOTOR_R_IN1
    porta: C
    pino: 8
    tipo: gpio
    direcao: saida
    boards: [carrinho]
    obs: Ponte H, direção do motor direito (lib/motor)
  - nome: MOTOR_R_IN2
    porta: A
    pino: 5
    tipo: gpio
    direcao: saida
    boards: [carrinho]
    obs: Ponte H, direção do motor direito (lib/motor)
  - nome: MOTOR_R_ENB
    porta: A
    pino: 4
    tipo: pwm
    direcao: pwm
    canal_tpm: 1
    boards: [carrinho]
    obs: TPM0_CH1, velocidade do motor direito, via lib/pwm_z42 (canal corrigido — ver debug/debug_ponte_H_encoder/src/main.c)

  # ── Ultrassom HC-SR04 (só Carrinho) ──────────────────────────────
  - nome: ULTRASSOM_TRIG
    porta: D
    pino: 3
    tipo: gpio
    direcao: saida
    boards: [carrinho]
    obs: HC-SR04 trigger (lib/ultrassom)
  - nome: ULTRASSOM_ECHO
    porta: D
    pino: 1
    tipo: gpio
    direcao: entrada_irq
    boards: [carrinho]
    obs: HC-SR04 echo, interrupção de borda (lib/ultrassom)
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

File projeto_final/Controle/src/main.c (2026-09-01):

/*
 * PSI3422 — projeto_final / Controle
 *
 * Base: experiências/Exp2_PSI3422/Controle. Lê comandos de um teclado
 * (via UART0/USB-serial, `script/controle_serial.py` ou `cat`/`screen`
 * no /dev/ttyACM0) e reenvia por rádio nRF24L01+ para o Carrinho;
 * recebe telemetria de volta e imprime uma linha legível por pacote.
 * Pinos: ver ../../pinmap.h (gerado, ver ../../pinmap.yaml). Ver
 * ../Carrinho/src/main.c para a explicação completa da arquitetura
 * híbrida (por que SPI é bare-metal aqui, não Zephyr nativo).
 *
 * Não usa pwm_z42 — este board não tem motor, só rádio + UART.
 *
 * Teclas RUN ('o') e STOP ('x'/espaço) já existiam em Exp2_PSI3422
 * (auto_mode/freio) e cobrem a semântica pedida no roteiro da Aula
 * 5/6 sem precisar de campo novo em protocol.h — só ganharam nome
 * explícito aqui. 'i' (mostrar distância) e 'c' (apagar distância)
 * são novas, ver key_to_cmd() e o bloco de leitura de tecla em main().
 */

#include <zephyr.h>
#include <device.h>
#include <drivers/gpio.h>
#include <drivers/uart.h>
#include <drivers/adc.h>
#include <sys/printk.h>

#include "nrf24.h"
#include "../../protocol.h"
#include "../../pinmap.h"

/*
 * ── Joystick (ADC) ───────────────────────────────────────────
 * X/Y/canais em ../../pinmap.h (JOYSTICK_X_CHANNEL/JOYSTICK_Y_CHANNEL),
 * botão de freio em JOYSTICK_BTN_PORT/PIN. Padrão de aquisição
 * (adc_channel_cfg + adc_sequence de 1 canal, lido sob demanda)
 * copiado de PSI3441/entregas/4/src/main.c — mesma placa/framework,
 * só trocamos "acender LED" por "converter em velocidade de motor".
 *
 * AVISO: nesta bancada o eixo do joystick já foi visto preso em
 * 3,3 V / 4095 (potenciômetro ou fiação com defeito, ver
 * PENDENCIAS.md do Exp2_PSI3422). Com hardware bom, zona morta em
 * torno do centro evita drift; com hardware defeituoso, ml/mr vão
 * saturar e o joystick some com o controle por UART — confira a
 * leitura antes de confiar neste caminho.
 */
#define JOYSTICK_ADC_RESOLUTION 12
#define JOYSTICK_CENTER         2048
#define JOYSTICK_DEADZONE       200

static const struct adc_channel_cfg joystick_x_cfg = {
    .gain             = ADC_GAIN_1,
    .reference        = ADC_REF_VDD_1,
    .acquisition_time = ADC_ACQ_TIME_DEFAULT,
    .channel_id       = JOYSTICK_X_CHANNEL,
    .differential     = 0,
};
static const struct adc_channel_cfg joystick_y_cfg = {
    .gain             = ADC_GAIN_1,
    .reference        = ADC_REF_VDD_1,
    .acquisition_time = ADC_ACQ_TIME_DEFAULT,
    .channel_id       = JOYSTICK_Y_CHANNEL,
    .differential     = 0,
};

static const struct device *joystick_adc;
static struct gpio_dt_spec joystick_btn;
static bool joystick_hw_ready;
static int16_t joystick_adc_buf;
static struct adc_sequence joystick_seq = {
    .buffer      = &joystick_adc_buf,
    .buffer_size = sizeof(joystick_adc_buf),
    .resolution  = JOYSTICK_ADC_RESOLUTION,
};

#define VELOCIDADE_PADRAO 16000
#define VELOCIDADE_GIRO   12000

static int16_t clamp_motor(int32_t v)
{
    if (v > INT16_MAX) return INT16_MAX;
    if (v < INT16_MIN) return INT16_MIN;
    return (int16_t)v;
}

/* raw 0..4095 (centro ~2048) -> -32768..32752, com zona morta central */
static int16_t adc_to_motor(int32_t raw)
{
    int32_t centered = raw - JOYSTICK_CENTER;
    if (centered > -JOYSTICK_DEADZONE && centered < JOYSTICK_DEADZONE) {
        return 0;
    }
    return clamp_motor(centered * 16);
}

/* Y = aceleração, X = curva; mixagem arcade (mesma convenção de key_to_cmd). */
static void joystick_read(int16_t *ml, int16_t *mr, bool *brk)
{
    if (!joystick_hw_ready) {
        *ml = 0;
        *mr = 0;
        *brk = false;
        return;
    }

    joystick_seq.channels = BIT(JOYSTICK_X_CHANNEL);
    int32_t x_raw = (adc_read(joystick_adc, &joystick_seq) == 0) ? joystick_adc_buf : JOYSTICK_CENTER;

    joystick_seq.channels = BIT(JOYSTICK_Y_CHANNEL);
    int32_t y_raw = (adc_read(joystick_adc, &joystick_seq) == 0) ? joystick_adc_buf : JOYSTICK_CENTER;

    int32_t throttle = adc_to_motor(y_raw);
    int32_t turn     = adc_to_motor(x_raw);

    *ml = clamp_motor(throttle + turn);
    *mr = clamp_motor(throttle - turn);
    *brk = gpio_pin_get_dt(&joystick_btn) > 0; /* GPIO_ACTIVE_LOW já inverte: pressionado = 1 */
}

/*
 * Traduz uma tecla em um novo estado de comando (mantido para compatibilidade com UART)
 */
static bool key_to_cmd(uint8_t key, radio_cmd_t *cmd)
{
    switch (key) {
    case 'w': case 'W':
        cmd->auto_mode = false; cmd->freio = false;
        cmd->motor_l = VELOCIDADE_PADRAO; cmd->motor_r = VELOCIDADE_PADRAO;
        return true;
    case 's': case 'S':
        cmd->auto_mode = false; cmd->freio = false;
        cmd->motor_l = -VELOCIDADE_PADRAO; cmd->motor_r = -VELOCIDADE_PADRAO;
        return true;
    case 'a': case 'A':
        cmd->auto_mode = false; cmd->freio = false;
        cmd->motor_l = -VELOCIDADE_GIRO; cmd->motor_r = VELOCIDADE_GIRO;
        return true;
    case 'd': case 'D':
        cmd->auto_mode = false; cmd->freio = false;
        cmd->motor_l = VELOCIDADE_GIRO; cmd->motor_r = -VELOCIDADE_GIRO;
        return true;
    case 'q': case 'Q':
        cmd->auto_mode = false; cmd->freio = false;
        cmd->motor_l = 0; cmd->motor_r = 0;
        return true;
    case 'x': case 'X': case ' ':
        cmd->auto_mode = false; cmd->freio = true;  /* STOP */
        return true;
    case 'o': case 'O':
        cmd->auto_mode = true; cmd->freio = false;  /* RUN */
        return true;
    case 'c': case 'C':
        /*
         * Apagar distância percorrida: incrementa o contador de
         * borda (ver protocol.h). Um keypress = um incremento; o
         * valor novo continua sendo reenviado a cada ~20ms até a
         * próxima tecla, mas o Carrinho só zera no instante em que
         * detecta a mudança, não a cada pacote.
         */
        cmd->apagar_seq++;
        return true;
    default:
        return false; /* tecla ignorada, mantém o comando atual (inclui 'i', tratada em main()) */
    }
}
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

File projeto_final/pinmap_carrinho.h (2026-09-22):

#ifndef PROJETO_FINAL_PINMAP_CARRINHO_H_
#define PROJETO_FINAL_PINMAP_CARRINHO_H_

/*
 * GERADO por tools/gen_pinmap.py a partir de pinmap.yaml — não
 * editar à mão. Editar pinmap.yaml e rodar o gerador de novo.
 *
 * Inclui #define de todo pino usado por Carrinho e/ou Controle;
 * cada projeto usa só o subconjunto que precisa (ver pinmap.yaml,
 * campo `boards`, e Pinmap.md pra tabela por board). Pinos
 * tipo=doc (SPI/UART fixos) não geram define, só documentação.
 */

#include <device.h>

/* MOTOR_L_IN1 — Ponte H, direção do motor esquerdo (lib/motor) [carrinho] */
#define MOTOR_L_IN1_PORT DEVICE_DT_GET(DT_NODELABEL(gpiod))
#define MOTOR_L_IN1_PIN  0   /* PTD0 */

/* MOTOR_L_IN2 — Ponte H, direção do motor esquerdo (lib/motor) [carrinho] */
#define MOTOR_L_IN2_PORT DEVICE_DT_GET(DT_NODELABEL(gpioc))
#define MOTOR_L_IN2_PIN  9   /* PTC9 */

/* MOTOR_L_ENA — TPM0_CH2, velocidade do motor esquerdo, via lib/pwm_z42 (canal corrigido — ver debug/debug_ponte_H_encoder/src/main.c) [carrinho] */
#define MOTOR_L_ENA_GPIO GPIOD
#define MOTOR_L_ENA_PIN  2   /* PTD2 = TPM0_CH2 */
#define MOTOR_L_ENA_CH   2

/* MOTOR_R_IN1 — Ponte H, direção do motor direito (lib/motor) [carrinho] */
#define MOTOR_R_IN1_PORT DEVICE_DT_GET(DT_NODELABEL(gpioc))
#define MOTOR_R_IN1_PIN  8   /* PTC8 */

/* MOTOR_R_IN2 — Ponte H, direção do motor direito (lib/motor) [carrinho] */
#define MOTOR_R_IN2_PORT DEVICE_DT_GET(DT_NODELABEL(gpioa))
#define MOTOR_R_IN2_PIN  5   /* PTA5 */

/* MOTOR_R_ENB — TPM0_CH1, velocidade do motor direito, via lib/pwm_z42 (canal corrigido — ver debug/debug_ponte_H_encoder/src/main.c) [carrinho] */
#define MOTOR_R_ENB_GPIO GPIOA
#define MOTOR_R_ENB_PIN  4   /* PTA4 = TPM0_CH1 */
#define MOTOR_R_ENB_CH   1

/* ULTRASSOM_TRIG — HC-SR04 trigger (lib/ultrassom) [carrinho] */
#define ULTRASSOM_TRIG_PORT DEVICE_DT_GET(DT_NODELABEL(gpiod))
#define ULTRASSOM_TRIG_PIN  3   /* PTD3 */

/* ULTRASSOM_ECHO — HC-SR04 echo, interrupção de borda (lib/ultrassom) [carrinho] */
#define ULTRASSOM_ECHO_PORT DEVICE_DT_GET(DT_NODELABEL(gpiod))
#define ULTRASSOM_ECHO_PIN  1   /* PTD1 */

/* ENCODER_L — IR HW-201 esquerda (lib/encoder) [carrinho] */
#define ENCODER_L_PORT DEVICE_DT_GET(DT_NODELABEL(gpiod))
#define ENCODER_L_PIN  1   /* PTD1 */

/* ENCODER_R — IR HW-201 direita (lib/encoder) [carrinho] */
#define ENCODER_R_PORT DEVICE_DT_GET(DT_NODELABEL(gpioa))
#define ENCODER_R_PIN  16   /* PTA16 */

/* RADIO_CSN — chip-select manual do nRF24 (lib/nrf24) [carrinho+controle] */
#define RADIO_CSN_PORT DEVICE_DT_GET(DT_NODELABEL(gpiob))
#define RADIO_CSN_PIN  10   /* PTB10 */

/* RADIO_CE — lib/nrf24 [carrinho+controle] */
#define RADIO_CE_PORT DEVICE_DT_GET(DT_NODELABEL(gpioe))
#define RADIO_CE_PIN  31   /* PTE31 */

/* RADIO_IRQ — ativo em LOW (lib/nrf24) [carrinho+controle] */
#define RADIO_IRQ_PORT DEVICE_DT_GET(DT_NODELABEL(gpiob))
#define RADIO_IRQ_PIN  8   /* PTB8 */

/* LED_RED — active low [carrinho+controle] */
#define LED_RED_PORT DEVICE_DT_GET(DT_NODELABEL(gpiob))
#define LED_RED_PIN  18   /* PTB18 */

/* LED_GREEN — active low [carrinho+controle] */
#define LED_GREEN_PORT DEVICE_DT_GET(DT_NODELABEL(gpiob))
#define LED_GREEN_PIN  19   /* PTB19 */

/* JOYSTICK_X — ADC0_SE8 — defeito de hardware conhecido, ver PENDENCIAS.md [controle] */
#define JOYSTICK_X_CHANNEL 8   /* PTB0 = ADC0_SE8 */

/* JOYSTICK_Y — ADC0_SE9 [controle] */
#define JOYSTICK_Y_CHANNEL 9   /* PTB1 = ADC0_SE9 */

/* JOYSTICK_BTN — botão de freio, pull-up interno, active low [controle] */
#define JOYSTICK_BTN_PORT DEVICE_DT_GET(DT_NODELABEL(gpiob))
#define JOYSTICK_BTN_PIN  2   /* PTB2 */

#endif /* PROJETO_FINAL_PINMAP_CARRINHO_H_ */

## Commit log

2026-08-25 Reestrutura em experiências/ + lib/ compartilhada; entrega Atividade 2 (Exp2_PSI3422)
    Reorganiza exp/ (antiga estrutura duplicada Exp1/Exp2 em vários lugares)
    em experiências/<ExpN>_PSI3422, uma pasta por aula, e introduz lib/ na
    raiz para código reaproveitável entre experiências.
    Cura o que veio da branch bbf (protótipo Exp2_MVP, vários commits de
    agente de IA) e traz só o que sobrevive a revisão:
    - lib/nrf24 e lib/spi: promovidos pra raiz (idênticos entre Carrinho e
    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
2026-08-25 Promove motor/ e ultrassom/ (com pwm_z42/) pra lib/ compartilhada
    motor.c e ultrassom.c já eram totalmente parametrizados via
    gpio_dt_spec/TPM, sem pino fixo do Carrinho — candidatos naturais a
    reuso nas próximas experiências (Aulas 3-6 continuam no mesmo
    hardware). pwm_z42/ vem junto por ser dependência direta de motor.c
    e já ser compartilhado com outra disciplina (PSI3441).
    control_fsm/ fica privado ao Carrinho: é lógica de aplicação
    específica desta experiência (RUN/STOP, desvio automático), não um
    driver de hardware reutilizável.
    De quebra, corrige o nome de arquivo quebrado
    experiências/Exp3_PSI3422/README>md -> README.md.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
2026-08-25 Reabilita controle por joystick (ADC) no Controle
    joystick_read() nunca existiu de fato — era chamada comentada, sem
    implementação, com nota de que o eixo físico lia 3,3V/4095 fixo.
    Implementa a aquisição de verdade (adc_channel_cfg + adc_sequence de
    1 canal por vez, lido sob demanda), no mesmo padrão de
    PSI3441/entregas/4/src/main.c (mesma placa/framework): X=PTB0
    (ADC0_SE8), Y=PTB1 (ADC0_SE9), freio=PTB2 (GPIO com pull-up).
    Zona morta central (±200 em torno de 2048) absorve drift de
    potenciômetro; mixagem arcade (Y=aceleração, X=curva) converte em
    motor_l/motor_r na mesma escala de key_to_cmd. Mantém o aviso sobre o
    defeito de hardware já observado nesta bancada (eixo preso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
    [main.c]
2026-08-25 Substitui pack/unpack manual do payload por struct compartilhada
    Payload de comando/telemetria era um uint8_t[] com offsets escritos
    na mão (pack_cmd/unpack_cmd/pack_telemetry/unpack_telemetry, um por
    lado do rádio). Cria experiências/Exp2_PSI3422/protocol.h com
    radio_cmd_t/radio_telemetry_t (packed, mesmo padrão do exemplo
    Arduino/RF24 com struct + radio.write(&data, sizeof(data))) e faz os
    dois main.c sobrepor a struct direto no buffer de 32 bytes que o
    rádio já exige (nrf24_receive só aceita buffer >= 32; RX_PW_P0 fixo
    em 32 nos dois lados — o buffer bruto continua obrigatório, só o
    pack/unpack byte a byte que some).
    control_fsm_apply/watchdog (Carrinho) passam a usar radio_cm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
    [main.c]
2026-08-25 Adiciona firmwares de debug: validação de ADC do joystick e alinhamento de rodas
    Duas validações de bancada isoladas, pedidas antes de dar a Exp2 como
    fechada: a Exp2_PSI3422 real ainda não teve nem o joystick nem o
    alinhamento mecânico verificados de fato, só testados no papel.
    Ficam numa branch separada (debug/exp2-validacoes) em vez de main —
    são ferramentas de bring-up, não parte da entrega.
    - debug/JoystickCheck (flash no Controle): lê X/Y/freio do joystick
    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
2026-08-25 Adiciona monitor.py e corrige baud rate no README de debug
    monitor.py: painel serial (rich) que classifica a saída printk dos 4
    firmwares (Carrinho, Controle, JoystickCheck, AlinhamentoCheck) em
    métricas ao vivo, com --control pra repassar teclas pro Controle.
    README corrigido: baud é 115200 (current-speed do zephyr.dts gerado),
    não 9600 como estava documentado antes.
2026-08-25 Desabilita joystick_read() de novo: defeito de hardware confirmado
    debug/JoystickCheck (branch debug/exp2-validacoes) confirmou que o
    eixo do joystick continua travado perto de 3,3V/4095 nesta bancada
    (medido com multímetro também). Com joystick_read() ativo, ml fica
    quase sempre != 0 e a lógica de prioridade do loop passa a deixar o
    joystick "assumir" a cada volta sem tecla de UART — o carrinho
    giraria sozinho em vez de ficar parado esperando comando. Isso não é
    bug de código: os valores impressos batem exatamente com a conta
    esperada de adc_to_motor()/mixagem.
    Mantém a implementação intacta (só a chamada comentada), pra
    reativar em uma linha assim que o potenciômetro for cons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
    [main.c]
2026-08-25 Adiciona DutySweepCheck: torque de arranque por motor, independente
    Pedido depois do teste com AlinhamentoCheck mostrar o carrinho
    andando torto (uma roda com mais força que a outra). Conferi
    pwm_z42.c/motor.c antes de suspeitar de hardware: os dois canais TPM
    escrevem CnV/CnSC pelo mesmo código, só endereçando índices
    diferentes — duty comandado é garantidamente idêntico em registrador,
    então a assimetria observada não pode ser bug de firmware.
    DutySweepCheck testa cada motor sozinho (o outro freado), subindo o
    duty aos poucos a partir de 0 (degraus de 1500, ~1,5s cada) até o
    máximo, pra achar o duty mínimo em que cada roda sai do lugar (torque
    de arranque) com o carrinho no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
2026-08-25 Adiciona EncoderCheck e reserva pinos dos encoders IR HW-201 (PTD1/PTD3)
    Pedido pra usar os dois módulos IR HW-201 (contagem de rotação por
    roda) na calibragem inicial do carrinho — é literalmente o objetivo
    da Aula 4 do README, adiantado aqui como ferramenta de bancada.
    Pinos ainda não decididos fisicamente, então sugeri PTD1 (esquerda) e
    PTD3 (direita) e reservei em Pinmap.md, seguindo a Aula 3 ("defina os
    pinos antes de criar a placa"). De propósito NÃO em PORTB/PORTE:
    nesta subfamília KL25Z só PORTA e PORTC/PORTD têm vetor de
    interrupção de pino — bate exatamente com o problema relatado ao
    tentar usar gpioe como IRQ antes (não é bug de configuração, é
    limitação d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
2026-08-25 Auto_mode com 4 faixas de distância em vez de liga/desliga
    Antes era binário: só freava abaixo de 30cm, senão sempre reto — não
    desviava de nada. Substitui por 4 faixas sem sobreposição, definidas
    pelo usuário:
    d > 30cm -> segue em frente
    20cm < d <= 30cm -> vira à direita (pivô: motor_l frente, motor_r ré)
    4cm < d <= 20cm -> dá ré
    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
2026-08-25 Adiciona PENDENCIAS.md com o estado atual do Exp2_PSI3422
    Snapshot do que falta: hardware bloqueando (joystick com defeito
    confirmado, carrinho andando torto), o que ainda não foi testado na
    branch de debug (DutySweepCheck, EncoderCheck), o que está só aqui e
    não em main (reserva de pinos dos encoders), o auto_mode novo (main
    4b3ff74) que buildou mas nunca rodou em hardware real, e as próximas
    aulas do README (3, 4, 5/6) ainda não iniciadas.
    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
2026-09-01 Adiciona lib/encoder (HW-201, sentido via motor_t) e Exp4_PSI3422/CarrinhoBase
    Aula 4: contador de pulsos assinado para o encoder IR HW-201 por
    roda. Canal único (sem quadratura), então o sentido é inferido do
    último comando aplicado ao motor_t da mesma roda (frente soma, ré
    subtrai, ponto morto/freio ignora). Mesmo padrão de lib/motor e
    lib/ultrassom, documentado em lib/SPEC.md.
    CarrinhoBase (novo projeto PlatformIO, Exp4_PSI3422) demonstra a lib:
    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
2026-09-01 Adiciona lib/odometria (odometria diferencial) e calibração medida em bancada
    Nova lib compartilhada lib/odometria/: resolve a "questão de
    programação competitiva" do roteiro da Aula 4 (dados os dois
    contadores de pulsos, calcular a distância percorrida) via odometria
    diferencial clássica. Pura aritmética, sem <math.h>/libm e sem
    nenhum #include de Zephyr — portável pra FRDM-KL25Z e um port futuro
    em ESP32.
    CarrinhoBase/src/main.c passa a zerar os encoders a cada segundo
    (encoder_reset) e alimentar odometria_atualiza(), imprimindo ângulo
    girado e distância percorrida junto com os pulsos brutos.
    Calibração física medida em bancada: raio da roda = 5 cm
    (RODA_RAIO_M, circunfer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
    [main.c]
2026-09-01 Adiciona debug/IRHW201_ESP32 (Exp4): bancada isolada do sensor IR HW-201 na ESP32
    Firmware caracteriza polaridade/bouncing do OUT do HW-201 na protoboard
    antes de confiar no GPIO_INT_EDGE_RISING assumido em lib/encoder. README
    em debug/ documenta fiação e formato de saída, seguindo o padrão do
    debug/README.md da Exp2_PSI3422.
    Claude-Session: https://claude.ai/code/session_01Lm71UdX5NRCcUgtrYcuK7p
2026-09-01 Documenta resultado de bancada do IRHW201_ESP32: HIGH=livre, LOW=interrompido
    Confirmado com sensor real: cada bloqueio gera 1 subida + 1 descida,
    então GPIO_INT_EDGE_RISING em lib/encoder não precisa mudar (só afeta
    a fase da contagem, não a quantidade de pulsos por volta).
    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
2026-09-01 Adiciona projeto_final: consolidação Carrinho+Controle pras Aulas 5/6
    Junta motores/ultrassom/rádio/control_fsm (Exp2) com encoders+odometria
    (Exp4) num único par de firmwares de produção. protocol.h ganha
    apagar_seq (comando) e dist_percorrida_cm (telemetria) pra cobrir
    RUN/STOP/mostrar distância/apagar distância do roteiro — RUN/STOP
    reaproveitam auto_mode/freio já existentes, sem campo novo.
    pinmap.yaml + tools/gen_pinmap.py centralizam o portmap da FRDM-KL25Z
    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
2026-09-01 Move projeto KiCad da PCB pra projeto_final/kicad/
    experiências/Exp3_PSI3422/Kicad/ -> projeto_final/kicad/: Aula3_PCB.*
    (esquemático quase vazio, PCB já roteada), símbolo/footprint
    FRDM-KL25Z dedicados e design-block-lib-table. Junto do
    PSI3422_shield.kicad_sym gerado por tools/gen_pinmap.py — os dois
    ainda não foram reconciliados, documentado como próximo passo em
    kicad/README.md (KiCad 9.0.2 já instalado nesta máquina agora).
    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
    [Aula3_PCB.kicad_pcb, Aula3_PCB.kicad_sch]
2026-09-15 novas coisas
    [caster.stl, chassis_plate.stl, freescale_kl25z_drilling_guide.stl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]
2026-09-22 Adiciona debug_ponte_H e debug_ponte_H_encoder: bancada de testes de motor DC + encoder
    Projetos standalone (PlatformIO/Zephyr, frdm_kl25z) pra validar ponte H
    (L298N) e encoder IR HW-201 antes de integrar em projeto_final:
    - debug_ponte_H: firmware de estado estático (frente L/R/ambos, parado)
    pra sondagem com multímetro sem timing de loop; overlay de devicetree
    habilitando gpioc (vem "disabled" por padrão no dtsi do KL25Z);
    trim de duty por lado pra compensar diferença mecânica entre motores.
    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
2026-09-22 Corrige canais PWM cruzados, leitura dupla do ultrassom e timeout do nrf24; adiciona lib/volante e bancada de debug rádio+encoder
    - pinmap.yaml: MOTOR_L_ENA/MOTOR_R_ENB tinham os canais TPM0 trocados
    (confirmado contra MKL25Z128VLK4-pinctrl.dtsi) — já corrigido em
    debug/debug_ponte_H_encoder mas nunca propagado pra produção.
    pinmap.h/Pinmap.md regerados via gen_pinmap.py.
    - control_fsm.c: auto_mode chamava ultrassom_read() de novo (main.c já
    tinha lido nesse ciclo), dobrando a latência da malha de desvio.
    - lib/nrf24: nrf24_receive() ignorava o parâmetro timeout (sempre
    100ms fixo); nrf24_set_auto_ack() novo, usado por Monitoramento pra
    não responder ACK junto com o Con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
    [main.c, pinmap.h, pinmap.yaml]
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2026-09-22 Corrige RADIO_SCK/MOSI/MISO em pinmap.yaml (PTC5/6/7, não PTD6/PTB9/PTD7) e adiciona debug_projeto_final_controle
    - pinmap.yaml documentava RADIO_SCK/MOSI/MISO como PTD6/PTB9/PTD7, mas
    nrf24_init() chama spi_init(SPI_0, ALT_0, ...) (lib/spi/spi.c), que
    hardcoda PTC5/PTC6/PTC7 via CMSIS direto — as únicas duas rotas de
    hardware do SPI0 na KL25Z são PORTC (ALT_0) ou PORTA (ALT_1), então
    PTD6/PTB9 nunca foi opção válida (erro de digitação antigo, não uma
    rota alternativa real). Corrigido pinmap.yaml/Pinmap.md/símbolo
    KiCad — são pinos tipo=doc, então não muda nenhum binário, só
    documentação. Se o shield físico foi roteado pelos valores antigos,
    o SPI do r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
    [pinmap.yaml]
2026-09-22 Bifurca pinmap_carrinho.yaml (PCB já fabricada) de pinmap.yaml (Controle, fiado depois do fix); adiciona nrf24_read_status()
    - A PCB do Carrinho já existia antes do fix de RADIO_SCK/MOSI/MISO
    (commit anterior) e foi roteada em cima do pinmap de antes dele
    (commit 6e70945: PTD6/PTB9/PTD7). O Controle foi fiado à mão depois
    do fix, seguindo o pinmap.yaml atual (PTC5/PTC6/PTC7).
    pinmap_carrinho.yaml é um fork só desses 3 pinos — resto
    (motor/ultrassom/encoder/CE/CSN/IRQ/LED, incluindo o fix de canal
    TPM dos motores, que é bug de silício e não de PCB) continua
    idêntico. tools/gen_pinmap.py aceita agora um YAML alternativo como
    argumento e deriva os nomes de saída (pi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
    [gen_pinmap.py, pinmap_carrinho.h, pinmap_carrinho.yaml]
2026-09-22 projeto_final/Carrinho: usa pinmap_carrinho.h e propaga fix de orientação do motor R
    - ../../pinmap.h -> ../../pinmap_carrinho.h: esta PCB já fabricada
    segue o pinmap de antes do fix de RADIO_SCK/MOSI/MISO (ver
    pinmap_carrinho.yaml); pinmap.yaml atual vale só pro Controle.
    - motor_init(&motor_r, ...): r_in1/r_in2 invertidos pra r_in2/r_in1 —
    motor R girava ao contrário do esperado em bancada, fix validado em
    debug_projeto_final ("orientar rodas"), agora também em produção.
    Claude-Session: https://claude.ai/code/session_01EZzQKL5aFE7o5G5kyCTGyC
    [main.c]
2026-09-22 debug_projeto_final*: unifica em pinmap_carrinho.h, calibração de bancada (PULSOS_POR_VOLTA=7, k_msleep(150), TRIM_L=11000, VELOCIDADE_AUTO=INT16_MAX)
    - Carrinho e Controle passam a usar pinmap_carrinho.h (não pinmap.h) —
    referência única pros dois lados agora: é o pinmap de antes do fix
    de RADIO_SCK/MOSI/MISO (commit 6e70945), que é o que está na PCB de
    verdade.
    - PULSOS_POR_VOLTA 1 -> 7: recalibrado contra o encoder/disco real.
    - k_msleep(150) no fim do loop do Carrinho (era 50): dá tempo do
    carrinho completar o pivô de curva/ré antes da próxima decisão.
    - TRIM_L 3000 -> 11000, VELOCIDADE_AUTO INT16_MAX/2 -> INT16_MAX:
    recalibrados em bancada.
    - Print de telemetria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
2026-09-22 Corrige nrf24_init() sempre retornando -ENOTSUP: RADIO_IRQ (PORTB) não suporta gpio_pin_interrupt_configure neste framework
    Causa raiz provável de todo o histórico de "rádio não conecta":
    nrf24_init() chamava gpio_pin_interrupt_configure_dt() em RADIO_IRQ
    (PTB8, PORTB). Neste board/framework (dts/arm/nxp/nxp_kl25z.dtsi), só
    gpioa/gpiod têm a property `interrupts` na devicetree — gpiob/gpioc/
    gpioe não; o driver (drivers/gpio/gpio_mcux.c) só liga GPIO_INT_ENABLE
    quando essa property existe, e sem ela a chamada retorna -ENOTSUP
    (-134) pra qualquer pino do port. Como RADIO_IRQ está em PORTB, isso
    sempre falhava, e nrf24_init() abortava ali (if (ret < 0) return ret)
    antes de chamar n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
2026-10-13 parte_2/aula2: script de uso da Aula 2
    aula2.sh reune o roteiro da aula num comando so': status do ambiente, build,
    e um alvo por licao (blink/pwm/parar/cam/vid/server/client). Detecta se esta
    no Raspberry ou no computador e escolhe as flags de compilacao.
    Detalhes que o script resolve:
    - 'compila' do Cekeikon so' existe em shell interativo (vem do .bashrc), entao
    o script carrega o ambiente na mao para funcionar por ssh;
    - o inst-cek5-raspberry.sh referencia $LD_LIBRARY_PATH sem guarda, o que mata
    um shell com 'set -u' - relaxamos -u/-e apenas durante o source;
    - sem Cekeikon (caso do notebook) cai num g++ equivalente, ja com o shim das
    constantes CV_BGR2GRAY/CV_GRAY2BGR que o OpenCV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
2026-10-13 parte_2/aula2.sh: cai no g++ quando o compila falha, e ativa o Cekeikon certo
    Build no Mint abortava com "line 40: <pid> aborted" - SIGABRT (saida 134) do
    proprio 'compila', nao do script. Causa: o script carregava sempre o
    inst-cek5-raspberry.sh, inclusive num PC x86_64. Cada arquitetura tem o seu:
    ativa_cekcpu no Mint, inst-cek5-raspberry.sh no Raspberry. Agora escolhe pela
    saida de 'uname -m'.
    Como o caminho do g++ ja' resolve, ele deixa de ser so' fallback de maquina
    sem Cekeikon e passa a ser a rede de seguranca: se o 'compila' falhar por
    qualquer motivo, o script mostra o status de saida e refaz com g++ sozinho.
    Dois controles novos:
    SEM_CEKEIKON=1 ignora o compila e vai direto d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
2026-10-27 aula4: corrige o mapeamento das rodas (lado e sentido trocados)
    Teste roda a roda em 27/10: os pinos 0,1 movem a roda esquerda (frente
    no 1) e os pinos 2,3 a direita (frente no 2). Com o mapeamento antigo o
    carrinho virava para o lado oposto ao da placa. Corrige tambem o
    servidor2 da aula 3, que usava o mesmo mapeamento.
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
